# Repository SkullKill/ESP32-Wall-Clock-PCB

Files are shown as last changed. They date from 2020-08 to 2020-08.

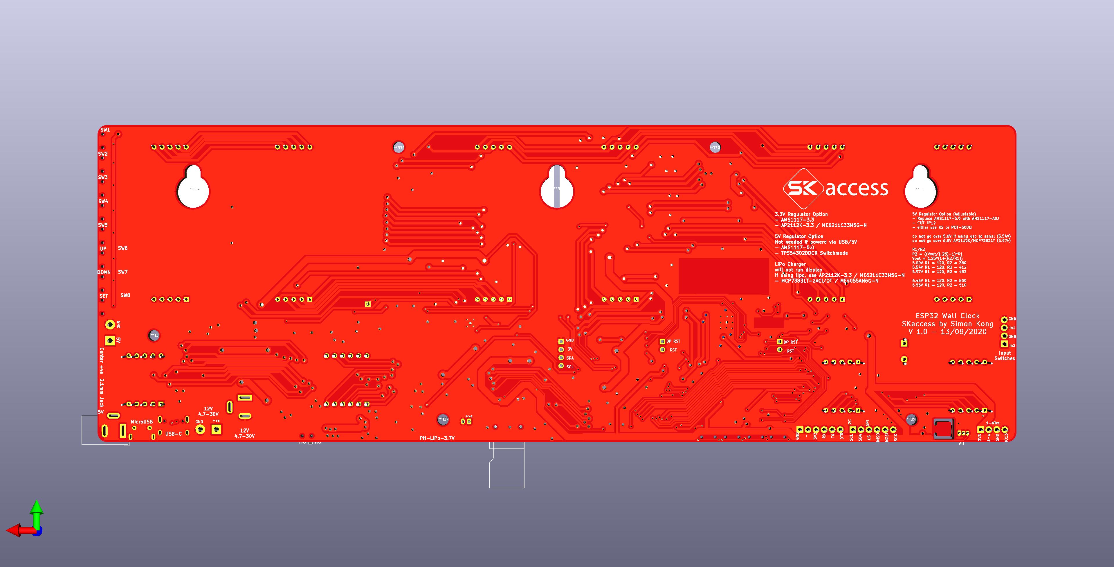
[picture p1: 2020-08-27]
ESP32-Wall-Clock/ESP32-Wall-Clock-Back-V1.0.jpg

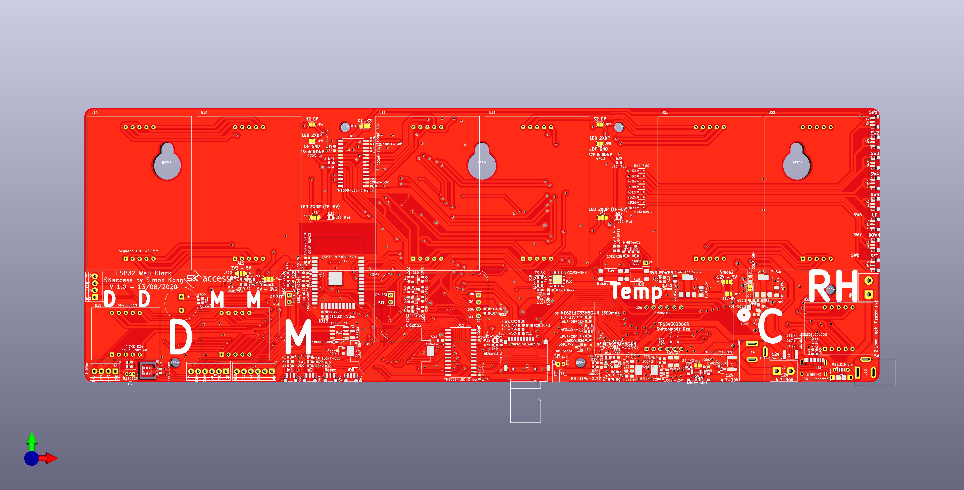
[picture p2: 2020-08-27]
ESP32-Wall-Clock/ESP32-Wall-Clock-Front-BoardOnly-V1.0.jpg

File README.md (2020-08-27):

# ESP32-Wall-Clock-PCB
ESP32 based 30cm Wall Mounted Clock. WiFi, NTP, SNMP, web interface, MicroUsb, Type-C, HG3613 Retrofit

Can be retrofitted into a HG3613 Case, or use standalone with the wall mounting on the pcb, or in a 3D Printed Case.

3D Printable Case not done yet...

this is still a work in progress.

PCB itself should be final, but the software is still being worked on. 

e.g Code for the light sensitivity sensor to automaticly adjust the display intensity

RTC PCF8563T code. 

OLED coding, etc....

ESP32-Wall-Clock-01.jpg


ESP32-Wall-Clock-Front-RT-V1.0a-WithOLEDboard.jpg


## V 1.0 26/08/2020 - Initial Release

  ------------------------------------------------------------
## PCB Board Used

Ready to use PCB Board (no up yet)

https://www.skstore.com.au/electronics/pcb/ESP32-Wall-Clock

PCB Design Files / gerber files

[ESP32-Wall-Clock-PCB](https://github.com/SkullKill/ESP32-Wall-Clock-PCB)

3D Printed Case design files / STL (no up yet)

[ESP32-Wall-Clock-PCB](https://github.com/SkullKill/ESP32-Wall-Clock-PCB)

FYI Gerber files are in the release section

https://github.com/SkullKill/ESP32-Wall-Clock-PCB/releases

more pictures in the wiki

https://github.com/SkullKill/ESP32-Wall-Clock-PCB/wiki

ESP32-Wall-Clock-HG3613-Retrofit-04.jpg


  ------------------------------------------------------------
## Schematics

ESP32-Wall-Clock-schematics-01-V1.0a.jpg


ESP32-Wall-Clock-schematics-02-V1.0.jpg


ESP32-Wall-Clock-schematics-03-V1.0.jpg


  ------------------------------------------------------------
## MecanicalDrawing

(Not Done Yet)

  ------------------------------------------------------------
## Code Used
(Not Done Yet)
[ESP32-Wall-Clock](https://github.com/SkullKill/ESP32-Wall-Clock)

  ------------------------------------------------------------

PCB features

* ESP32 Microprocessor
* onboard, IO0 / Reset switches
* breakout for UART (Programming/Serial monitor), i2c, SPI, 1-wire
* 5V input via MicroUSB, USB Type-C, 2.1mm barrel, Screw Type Terminal
* OR 5.6V to 26V if using Switchmode Reg, OR 6.4V-30V if using AMS1117-5.0 (input via 2.1mm barrel or Screw Type Terminal)
* PCF8563T RTC Clock with CR2032 Coin Cell Battery
* CP2102 USB to Serial, with Auto Reset (optional)
* RTC clock
* ALS-PT19 Light Intensity Sensor, to adjust Screen Brightness
* AHT20 Temperature / Humidity Sensor
* 1-Wire provision (possibility to add a number of DS18B20 temperature sensors)
* Built in buzzer
* 1-wire rail (possibility to add a number of DS18B20 temperature sensors)
* 2 physical button, + 8 physical button via TM1638, using diode, so that multiple button can be pressed at the same time.
* Ability to add external buttons.
* 1 configurable status light. (IO 13)
* 2 X TM1638 LED Segment Display Driver (in Common Anode Mode) [ one driving 6 digit, one driving 10 digit ]
* 6 X 1.8" / 45mm Segment display for Time Display (Common Anode Mode)
* 0.56" / 14.22mm Segment display for Date/Month / Temperature/Humidity (Common Anode Mode)
* Micro SD Card Slot
* Reverse polarity protection on 12V input
* PTC Fuse
* Level Shifter for ESP32 - TM1638 Comms

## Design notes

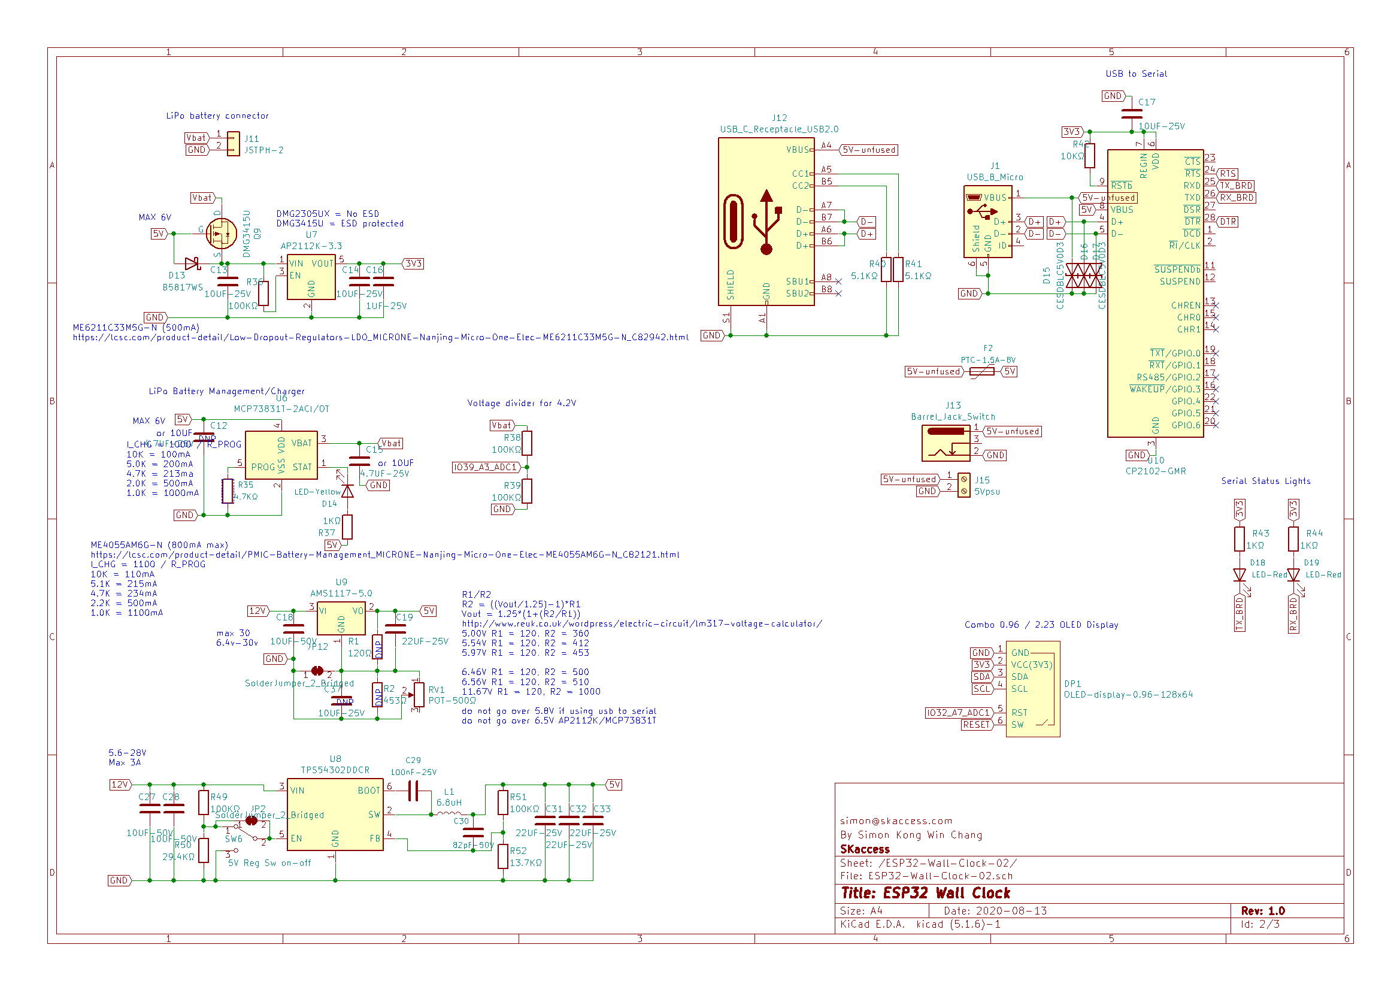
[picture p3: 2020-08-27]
ESP32-Wall-Clock/ESP32-Wall-Clock-schematics-02-V1.0.jpg

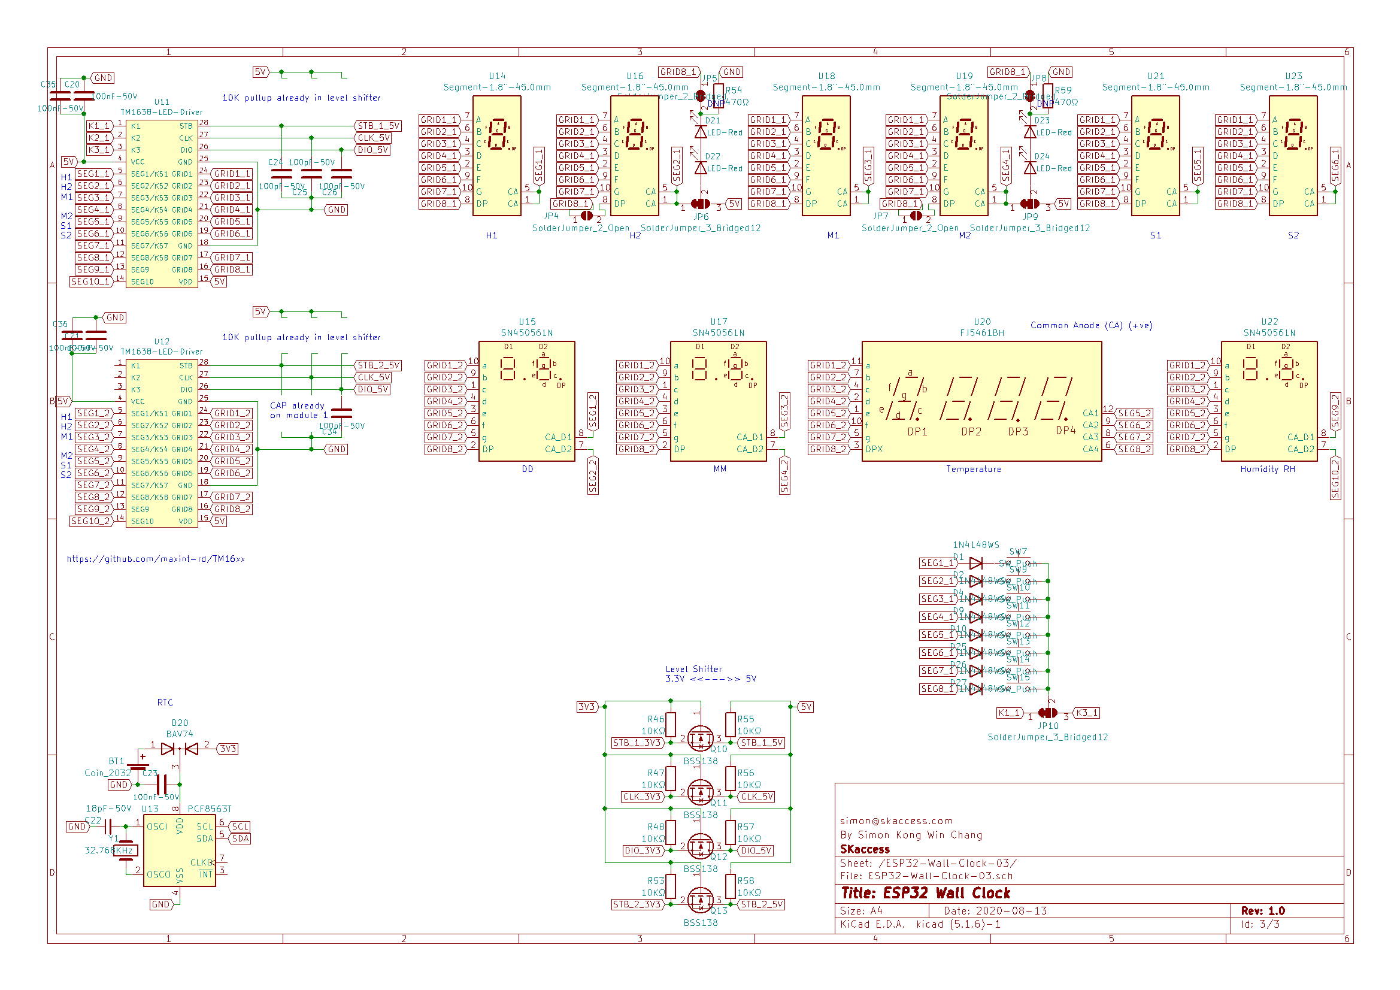
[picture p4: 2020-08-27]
ESP32-Wall-Clock/ESP32-Wall-Clock-schematics-03-V1.0.jpg

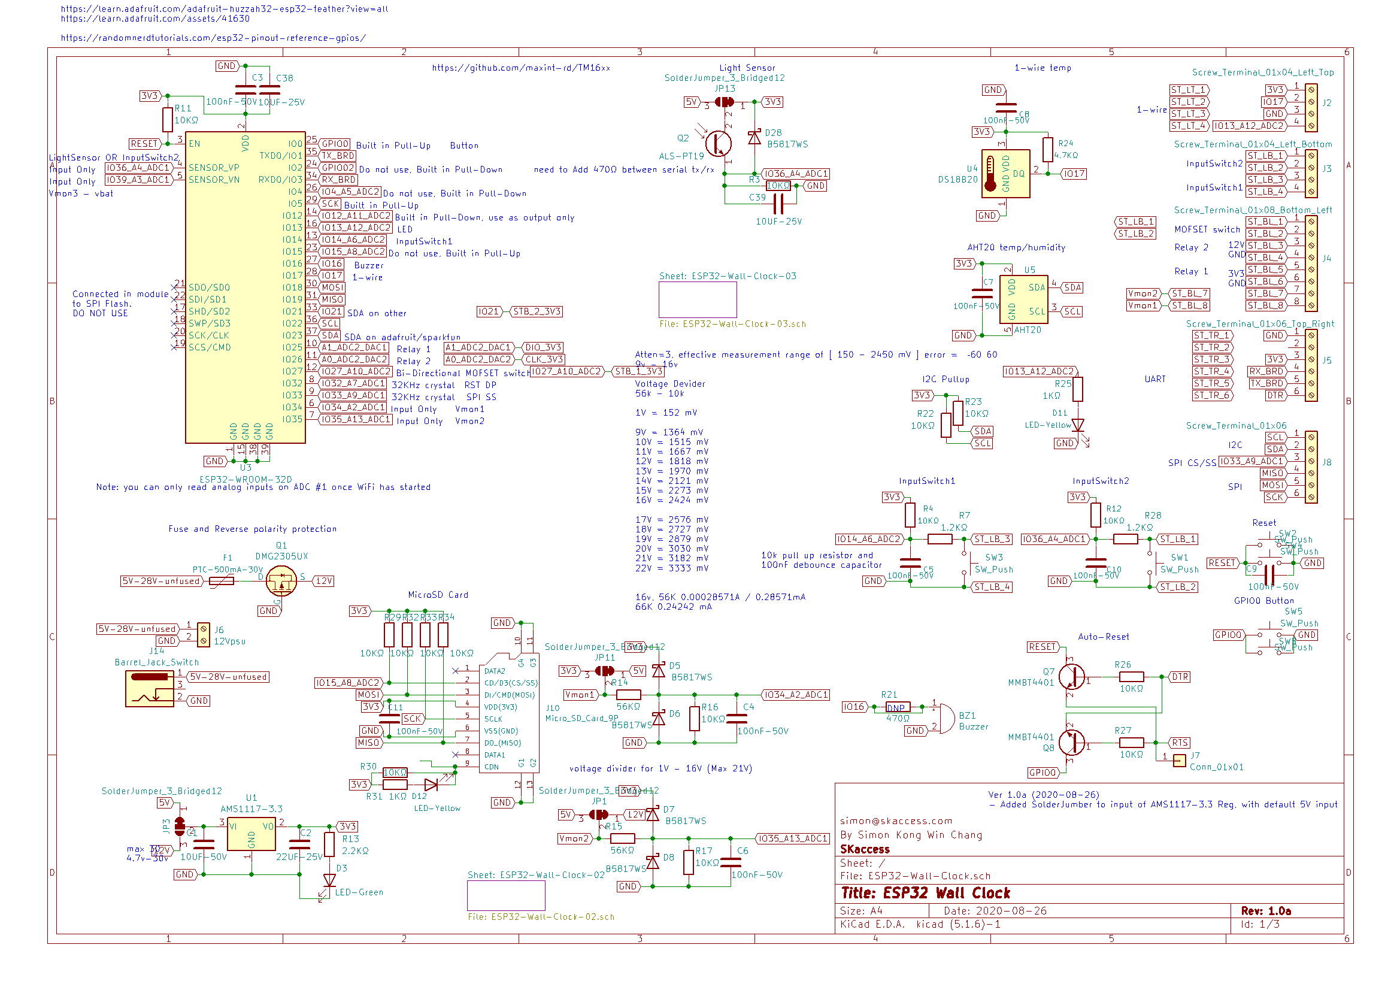
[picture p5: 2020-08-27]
ESP32-Wall-Clock/ESP32-Wall-Clock-schematics-01-V1.0a.jpg

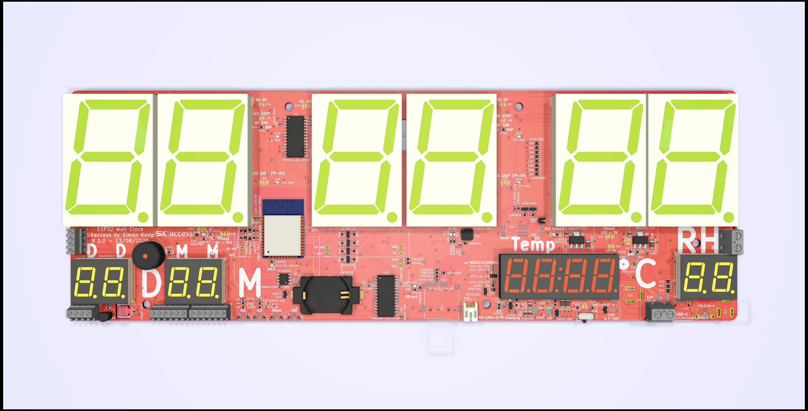
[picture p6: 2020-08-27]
ESP32-Wall-Clock/ESP32-Wall-Clock-Front-RT-V1.0.jpg

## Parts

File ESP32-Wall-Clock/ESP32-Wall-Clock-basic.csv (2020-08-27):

Reference | Quantity | Value | Footprint | Datasheet | LCSC | LCSCweb | MPN | MPNweb | web | ALT | at | removed
BT1 | 1 | Coin_2032 | Battery:BatteryHolder_Keystone_1060_1x2032 | https://datasheet.lcsc.com/szlcsc/1811061923_Q-J-CR2032-BS-6-1_C70377.pdf | C70377 | https://lcsc.com/product-detail/Battery-Holders-Clips-Contacts_Button-battery-holder-CR2032_C70377.html | CR2032-BS-6-1 |  |  | C238069
BZ1 | 1 | Buzzer | ESP32-12V-Voltage-Monitor:Buzzer_12x9.5RM5.0 | https://datasheet.lcsc.com/szlcsc/ZLFY-ZL-YDW1207-4005PA-5-0_C219727.pdf | C219727 | https://lcsc.com/product-detail/Buzzers_ZLFY-ZL-YDW1207-4005PA-5-0_C219727.html | ZL-YDW1207-4005PA-5.0
C1 C18 | 2 | 10UF-50V | Capacitor_SMD:C_1206_3216Metric | https://datasheet.lcsc.com/szlcsc/Samsung-Electro-Mechanics-CL31A106KBHNNNE_C13585.pdf | C13585 | https://lcsc.com/product-detail/Multilayer-Ceramic-Capacitors-MLCC-SMD-SMT_SAMSUNG_CL31A106KBHNNNE_10uF-106-10-50V_C13585.html | CL31A106KBHNNNE |  |  |  | reg | switchmode
C12 C15 | 0 | 4.7UF-25V | Capacitor_SMD:C_0603_1608Metric | https://datasheet.lcsc.com/szlcsc/1811110921_Samsung-Electro-Mechanics-CL10A106MA8NRNC_C96446.pdf | C69335 | https://lcsc.com/product-detail/Multilayer-Ceramic-Capacitors-MLCC-SMD-SMT_SAMSUNG_CL10A475KA8NQNC_4-7uF-475-10-25V_C69335.html | CL10A475KA8NQNC |  |  |  |  | charger
C16 | 0 | 1UF-25V | Capacitor_SMD:C_0603_1608Metric | https://datasheet.lcsc.com/szlcsc/1811071810_Samsung-Electro-Mechanics-CL10B105KA8NNNC_C29936.pdf | C29936 | https://lcsc.com/product-detail/Multilayer-Ceramic-Capacitors-MLCC-SMD-SMT_SAMSUNG_CL10B105KA8NNNC_1uF-105-10-25V-X7R_C29936.html | CL10B105KA8NNNC |  |  |  |  | AP2112K-3.3
C2 C19 | 2 | 22UF-25V | Capacitor_SMD:C_0805_2012Metric | https://datasheet.lcsc.com/szlcsc/Samsung-Electro-Mechanics-CL21A226MAQNNNE_C45783.pdf | C45783 | https://lcsc.com/product-detail/Multilayer-Ceramic-Capacitors-MLCC-SMD-SMT_SAMSUNG_CL21A226MAQNNNE_22uF-226-20-25V_C45783.html | CL21A226MAQNNNE |  |  | C86816 | reg | switchmode
C22 | 1 | 18pF-50V | Capacitor_SMD:C_0402_1005Metric | https://datasheet.lcsc.com/szlcsc/1811081533_Murata-Electronics-GCM1555C1H180JA16D_C126499.pdf | C126499 | https://lcsc.com/product-detail/Multilayer-Ceramic-Capacitors-MLCC-SMD-SMT_Murata-Electronics-GCM1555C1H180JA16D_C126499.html | GCM1555C1H180JA16D |  |  |  | RTC
C24 C25 C26 C34 | 4 | 100pF-50V | Capacitor_SMD:C_0402_1005Metric | https://datasheet.lcsc.com/szlcsc/1810191214_Samsung-Electro-Mechanics-CL05C101JB5NNNC_C26409.pdf | C26409 | https://lcsc.com/product-detail/Multilayer-Ceramic-Capacitors-MLCC-SMD-SMT_SAMSUNG_CL05C101JB5NNNC_100pF-101-5-50V_C26409.html | CL05C101JB5NNNC |  |  |  | TM1638
C29 | 0 | 100nF-25V | Capacitor_SMD:C_0402_1005Metric | https://datasheet.lcsc.com/szlcsc/1811141111_Samsung-Electro-Mechanics-CL05A104KA5NNNC_C100072.pdf | C100072 | https://lcsc.com/product-detail/Multilayer-Ceramic-Capacitors-MLCC-SMD-SMT_SAMSUNG_CL05A104KA5NNNC_100nF-104-10-25V_C100072.html | CL05A104KA5NNNC |  |  |  |  | switchmode
C30 | 0 | 82pF-50V | Capacitor_SMD:C_0402_1005Metric | https://datasheet.lcsc.com/szlcsc/Samsung-Electro-Mechanics-CL05C820JB5NNNC_C13532.pdf | C13532 | https://lcsc.com/product-detail/Multilayer-Ceramic-Capacitors-MLCC-SMD-SMT_SAMSUNG_CL05C820JB5NNNC_82pF-820-5-50V_C13532.html | CL05C820JB5NNNC |  |  |  |  | switchmode
C38 C39 | 2 | 10UF-25V | Capacitor_SMD:C_0603_1608Metric | https://datasheet.lcsc.com/szlcsc/1811110921_Samsung-Electro-Mechanics-CL10A106MA8NRNC_C96446.pdf | C96446 | https://lcsc.com/product-detail/Multilayer-Ceramic-Capacitors-MLCC-SMD-SMT_Samsung-Electro-Mechanics-CL10A106MA8NRNC_C96446.html | CL10A106MA8NRNC |  |  |  | ESP32, LightSensor | 5v var reg, 3.3v reg, usb serial
C5 C4 C3 C9 C8 C6 C7 C10 C20 C23 C21 C35 C36 | 13 | 100nF-50V | Capacitor_SMD:C_0603_1608Metric | https://datasheet.lcsc.com/szlcsc/YAGEO-AC0603KRX7R9BB104_C149620.pdf | C149620 | https://lcsc.com/product-detail/Multilayer-Ceramic-Capacitors-MLCC-SMD-SMT_YAGEO-AC0603KRX7R9BB104_C149620.html | AC0603KRX7R9BB104 |  |  |  |  | sd card
D1 D2 D4 D9 D10 D25 D26 D27 | 8 | 1N4148WS | Diode_SMD:D_SOD-323 | https://datasheet.lcsc.com/szlcsc/Changjiang-Electronics-Tech-CJ-1N4148WS_C2128.pdf | C2128 | https://lcsc.com/product-detail/Switching-Diode_Changjiang-Electronics-Tech-CJ-1N4148WS_C2128.html | 1N4148WS |  |  |  | switch array
D11 | 1 | LED-Yellow | LED_SMD:LED_0603_1608Metric | https://datasheet.lcsc.com/szlcsc/Foshan-NationStar-Optoelectronics-FC-DA1608HYK-588J_C84268.pdf | C84268 | https://lcsc.com/product-detail/Light-Emitting-Diodes-LED_Yellow-light-SMDLED-70-150mcd_C84268.html | FC-DA1608HYK-588J |  |  |  | io 13 | charger, SD card
D15 | 1 | CESDBLC5V0D3 | Diode_SMD:D_SOD-323 | https://datasheet.lcsc.com/szlcsc/1811122110_Changjiang-Electronics-Tech-CJ-CESDBLC5V0D3_C47346.pdf | C47346 | https://lcsc.com/product-detail/Diodes-ESD_Changjiang-Electronics-Tech-CJ-CESDBLC5V0D3_C47346.html | CESDBLC5V0D3 |  |  |  | usb power | usb data
D24 D23 D22 D21 | 4 | LED-Red | LED_SMD:LED_0603_1608Metric | https://datasheet.lcsc.com/szlcsc/Foshan-NationStar-Optoelectronics-FC-DA1608HRK-620D_C84263.pdf | C84263 | https://lcsc.com/product-detail/Light-Emitting-Diodes-LED_Red-LED-SMDLED-80-100mcd_C84263.html | FC-DA1608HRK-620D |  |  |  | clock dots | Serial tx/rx
D20 | 1 | BAV74 | Package_TO_SOT_SMD:SOT-23 | https://datasheet.lcsc.com/szlcsc/1809211016_Changjiang-Electronics-Tech-CJ-BAV74_C68981.pdf | C68981 | https://lcsc.com/product-detail/Switching-Diode_Changjiang-Electronics-Tech-CJ-BAV74_C68981.html | BAV74 |  |  |  | RTC
D3 | 0 | LED-Green | LED_SMD:LED_0603_1608Metric | https://datasheet.lcsc.com/szlcsc/Orient-ORH-G36G_C205443.pdf | C205443 | https://lcsc.com/product-detail/Light-Emitting-Diodes-LED_0603-green_C205443.html | ORH-G36G |  |  |  |  | power
D5 D6 D7 D8 | 4 | B5817WS | Diode_SMD:D_SOD-323 | https://datasheet.lcsc.com/szlcsc/1811051320_MDD-Microdiode-Electronics-B5817WS-SJ_C114023.pdf | C114023 | https://lcsc.com/product-detail/Schottky-Barrier-Diodes-SBD_MDD-Microdiode-Electronics-B5817WS-SJ_C114023.html | B5817WS-SJ |  |  |  | voltage divider | 3v3 reg
DP1 | 1 | OLED-display-0.96-128x64 | ESP32-Wall-Clock:OLED-display-0.96-128x64-2.23-128x32-combo
F1 | 1 | PTC-500mA-30V | Fuse:Fuse_1812_4532Metric | https://datasheet.lcsc.com/szlcsc/1912111437_Jinrui-Electronic-Materials-Co-JK-MSMD050-30_C369168.pdf | C369168 | https://lcsc.com/product-detail/PTC-Resettable-Fuses_Jinrui-Electronic-Materials-Co-JK-MSMD050-30_C369168.html | JK-MSMD050-30 |  |  |  | 12v input
F2 | 1 | PTC-1.5A-8V | Fuse:Fuse_1812_4532Metric | https://datasheet.lcsc.com/szlcsc/1810111821_Littelfuse-1812L150ZR_C207071.pdf | C207071 | https://lcsc.com/product-detail/Surface-Mount-Fuses_Littelfuse_1812L150ZR_Littelfuse-1812L150ZR_C207071.html | 1812L150ZR |  |  |  | 5v input
J1 | 1 | USB_B_Micro | ESP32-12V-Voltage-Monitor:USB_Micro-B_Korean_U-F-M5DD-Y-L | https://datasheet.lcsc.com/szlcsc/1811131825_Korean-Hroparts-Elec-U-F-M5DD-Y-L_C91146.pdf | C91146 | https://lcsc.com/product-detail/USB-Connectors_Korean-Hroparts-Elec-U-F-M5DD-Y-L_C91146.html | U-F-M5DD-Y-L
J10 | 0 | Micro_SD_Card_9P | ESP32-12V-Voltage-Monitor:Micro_SD_9+4P-SMD-16.1X14.5X1.85MM | https://datasheet.lcsc.com/szlcsc/2002271812_XKB-Connectivity-XKTF-015-N_C381082.pdf | C381082 | https://lcsc.com/product-detail/Card-Sockets-Connectors_XKB-Connectivity-XKTF-015-N_C381082.html | XKTF-015-N
J11 | 0 | JSTPH-2 | Connector_JST:JST_PH_S2B-PH-K_1x02_P2.00mm_Horizontal | http://boomele.com/proshow.asp?id=15 | C49992 | https://lcsc.com/product-detail/Wire-To-Board-Wire-To-Wire-Connector_BOOMELE-Boom-Precision-Elec-PH-2AWD_C49992.html | S2B-PH-K-S |  |  |  |  | lipo batt
J12 | 1 | USB_C_Receptacle_USB2.0 | Connector_USB:USB_C_Receptacle_HRO_TYPE-C-31-M-12 | https://datasheet.lcsc.com/szlcsc/1811131825_Korean-Hroparts-Elec-TYPE-C-31-M-12_C165948.pdf | C165948 | https://lcsc.com/product-detail/USB-Type-C_Korean-Hroparts-Elec-TYPE-C-31-M-12_C165948.html | TYPE-C-31-M-12
J14 J13 | 2 | Barrel_Jack_Switch | Connector_BarrelJack:BarrelJack_Wuerth_6941xx301002 | https://datasheet.lcsc.com/szlcsc/1811051112_BOOMELE-Boom-Precision-Elec-DC-005-5-5-2-0MM_C16214.pdf | C16214 | https://lcsc.com/product-detail/AC-DC-Power-Plugs-Receptacles_BOOMELE-Boom-Precision-Elec-DC-005-5-5-2-0MM_C16214.html | DC-005 5.5-2.0MM
J15 | 0 | 5Vpsu | pi-template:TerminalBlock_bornier-2_P5.08mm | https://datasheet.lcsc.com/szlcsc/Ningbo-Kangnex-Elec-WJ126V-5-0-2P_C8404.pdf | C8404 | https://lcsc.com/product-detail/Pluggable-System-Terminal-Block_Ningbo-Kangnex-Elec-WJ126V-5-0-2P_C8404.html | WJ126V-5.0-2P
J2 | 0 | Screw_Terminal_01x04_Left_Top | pi-template:TerminalBlock_TE_282834-4_1x04_P2.54mm_Horizontal | ~ |  |  | KF128-2.54-4P | http://en.cnkefa.com/index.php?c=product&id=159 | https://www.aliexpress.com/store/group/Connection-terminal/4657016_515213135.html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
J3 | 0 | Screw_Terminal_01x04_Left_Bottom | pi-template:TerminalBlock_TE_282834-4_1x04_P2.54mm_Horizontal | ~ |  |  | KF128-2.54-4P | http://en.cnkefa.com/index.php?c=product&id=159 | https://www.aliexpress.com/store/group/Connection-terminal/4657016_515213135.html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
J4 | 0 | Screw_Terminal_01x08_Bottom_Left | pi-template:TerminalBlock_TE_282834-8_1x08_P2.54mm_Horizontal | ~ |  |  | KF128-2.54-8P | http://en.cnkefa.com/index.php?c=product&id=159
J5 | 0 | Screw_Terminal_01x06_Top_Right | pi-template:TerminalBlock_TE_282834-6_1x06_P2.54mm_Horizontal | ~ |  |  | KF128-2.54-6P | http://en.cnkefa.com/index.php?c=product&id=159
J6 | 0 | 12Vpsu | pi-template:TerminalBlock_bornier-2_P5.08mm | https://datasheet.lcsc.com/szlcsc/Ningbo-Kangnex-Elec-WJ126V-5-0-2P_C8404.pdf | C8404 | https://lcsc.com/product-detail/Pluggable-System-Terminal-Block_Ningbo-Kangnex-Elec-WJ126V-5-0-2P_C8404.html | WJ126V-5.0-2P
J7 | 1 | Conn_01x01 | Connector_PinHeader_2.54mm:PinHeader_1x01_P2.54mm_Vertical | ~
J8 | 0 | Screw_Terminal_01x06 | pi-template:TerminalBlock_TE_282834-6_1x06_P2.54mm_Horizontal | ~ |  |  | KF128-2.54-6P | http://en.cnkefa.com/index.php?c=product&id=159
J9 | 0 | Screw_Terminal_01x02 | pi-template:TerminalBlock_TE_282834-2_1x02_P2.54mm_Horizontal | ~ |  |  | KF128-2.54-2P | http://en.cnkefa.com/index.php?c=product&id=159
JP1 JP11 JP13 JP9 JP6 JP10 | 6 | SolderJumper_3_Bridged12 | Jumper:SolderJumper-3_P1.3mm_Bridged12_RoundedPad1.0x1.5mm | ~
JP12 | 1 | SolderJumper_2_Bridged | Jumper:SolderJumper-2_P1.3mm_Bridged2Bar_RoundedPad1.0x1.5mm | ~
JP2 JP5 JP8 | 3 | SolderJumper_2_Bridged | Jumper:SolderJumper-2_P1.3mm_Bridged_RoundedPad1.0x1.5mm | ~
JP3 JP7 JP4 | 3 | SolderJumper_2_Open | Jumper:SolderJumper-2_P1.3mm_Open_RoundedPad1.0x1.5mm | ~
L1 | 0 | 6.8uH | ESP32-12V-Voltage-Monitor:L_7.3x7.3_H4.5 | https://datasheet.lcsc.com/szlcsc/1810181823_cjiang-Changjiang-Microelectronics-Tech-FXL0630-6R8-M_C167221.pdf | C167221 | https://lcsc.com/product-detail/Power-Inductors_cjiang-Changjiang-Microelectronics-Tech-FXL0630-6R8-M_C167221.html | FXL0630-6R8-M |  |  |  |  | switchmode
Q1 | 1 | DMG2305UX | Package_TO_SOT_SMD:SOT-23 | https://datasheet.lcsc.com/szlcsc/Diodes-Incorporated-DMG2305UX-13_C144153.pdf | C144153 | https://lcsc.com/product-detail/MOSFET_Diodes-Incorporated_DMG2305UX-13_Diodes-Incorporated-DMG2305UX-13_C144153.html | DMG2305UX-13 |  |  |  | 12v reverse polarity protection
Q10 Q11 Q12 Q13 | 4 | BSS138 | Package_TO_SOT_SMD:SOT-23 | https://datasheet.lcsc.com/szlcsc/Diodes-Incorporated-BSS138-7-F_C40912.pdf | C40912 | https://lcsc.com/product-detail/MOSFET_Diodes-Incorporated_BSS138-7-F_Diodes-Incorporated-BSS138-7-F_C40912.html | BSS138-7-F |  |  |  | level shifter
Q2 | 1 | ALS-PT19 | LED_SMD:LED_0603_1608Metric | https://datasheet.lcsc.com/szlcsc/1806131537_Everlight-Elec-ALS-PT19-315C-L177-TR8_C146233.pdf | C146233 | https://lcsc.com/product-detail/Photoresistors_ALS-PT19-315C-L177-TR8_C146233.html | ALS-PT19-315C/L177/TR8 |  |  |  | light sensor
Q8 Q7 | 0 | MMBT4401 | Package_TO_SOT_SMD:SOT-23 | https://datasheet.lcsc.com/szlcsc/ON-Semicon-ON-MMBT4401LT1G_C31776.pdf | C31776 | https://lcsc.com/product-detail/Transistors-NPN-PNP_ON-Semicon_MMBT4401LT1G_ON-Semicon-ON-MMBT4401LT1G_C31776.html | MMBT4401LT1G |  |  |  |  | auto reset
Q9 | 0 | DMG3415U | Package_TO_SOT_SMD:SOT-23 | https://datasheet.lcsc.com/szlcsc/1809191942_Diodes-Incorporated-DMG3415U-7_C96616.pdf | C96616 | https://lcsc.com/product-detail/MOSFET_Diodes-Incorporated_DMG3415U-7_Diodes-Incorporated-DMG3415U-7_C96616.html | DMG3415U-7 |  |  |  |  | charger
R1 | 0 | 120Ω | Resistor_SMD:R_0603_1608Metric | https://datasheet.lcsc.com/szlcsc/1811021219_YAGEO-RC0603FR-07120RL_C114640.pdf | C114640 | https://lcsc.com/product-detail/Chip-Resistor-Surface-Mount_YAGEO-RC0603FR-07120RL_C114640.html | RC0603FR-07120RL |  |  |  |  | 5v reg adj
R13 | 0 | 2.2KΩ | Resistor_SMD:R_0603_1608Metric | https://datasheet.lcsc.com/szlcsc/YAGEO-RC0603FR-072K2L_C114662.pdf | C114662 | https://lcsc.com/product-detail/Chip-Resistor-Surface-Mount_2-2KR-2201-1_C114662.html | RC0603FR-072K2L |  |  |  |  | 3v3 power
R14 R15 | 2 | 56KΩ | Resistor_SMD:R_0603_1608Metric | https://datasheet.lcsc.com/szlcsc/1811021312_YAGEO-RC0603FR-0756KL_C114630.pdf | C114630 | https://lcsc.com/product-detail/Chip-Resistor-Surface-Mount_YAGEO-RC0603FR-0756KL_C114630.html | RC0603FR-0756KL |  |  |  | voltage divider
R2 | 0 | 453Ω | Resistor_SMD:R_0603_1608Metric | https://datasheet.lcsc.com/szlcsc/2007151233_YAGEO-RC0603FR-07453RL_C482871.pdf | C482871 | https://lcsc.com/product-detail/New-Arrivals_YAGEO-RC0603FR-07453RL_C482871.html | RC0603FR-07453RL |  |  |  |  | 5v reg adj
R21 R54 R59 | 0 | 470Ω | Resistor_SMD:R_0603_1608Metric | https://datasheet.lcsc.com/szlcsc/1810161617_YAGEO-RC0603FR-07470RL_C114669.pdf | C114669 | https://lcsc.com/product-detail/Chip-Resistor-Surface-Mount_YAGEO-RC0603FR-07470RL_C114669.html | RC0603FR-07470RL |  |  |  |  | buzzer, clock dot
R24 | 1 | 4.7KΩ | Resistor_SMD:R_0603_1608Metric | https://datasheet.lcsc.com/szlcsc/YAGEO-RC0603FR-074K7L_C99782.pdf | C99782 | https://lcsc.com/product-detail/Chip-Resistor-Surface-Mount_4-7KR-472-1_C99782.html | RC0603FR-074K7L |  |  |  | 1-wire | charger
R25 | 1 | 1KΩ | Resistor_SMD:R_0603_1608Metric | https://datasheet.lcsc.com/szlcsc/YAGEO-RC0603FR-071KL_C22548.pdf | C22548 | https://lcsc.com/product-detail/Chip-Resistor-Surface-Mount_1KR-1001-1_C22548.html | RC0603FR-071KL |  |  |  | io13 | serial tx/rx, microSD, charger
 | 0 | 100KΩ | Resistor_SMD:R_0603_1608Metric | https://datasheet.lcsc.com/szlcsc/1809281124_YAGEO-RC0603FR-07100KL_C14675.pdf | C14675 | https://lcsc.com/product-detail/Chip-Resistor-Surface-Mount_100KR-1003-1_C14675.html | RC0603FR-07100KL |  |  |  |  | 3v3 reg, bat voltage divider, switchmode
R4 R16 R11 R17 R22 R23 R12 R3 R46 R55 R47 R56 R48 R57 R53 R58 | 16 | 10KΩ | Resistor_SMD:R_0603_1608Metric | https://datasheet.lcsc.com/szlcsc/YAGEO-RC0603FR-0710KL_C98220.pdf | C98220 | https://lcsc.com/product-detail/Chip-Resistor-Surface-Mount_10KR-1002-1_C98220.html | RC0603FR-0710KL |  |  |  |  | usbSerial, Sdcard, autoReset
R40 R41 | 2 | 5.1KΩ | Resistor_SMD:R_0603_1608Metric | https://datasheet.lcsc.com/szlcsc/YAGEO-RC0603FR-075K1L_C105580.pdf | C105580 | https://lcsc.com/product-detail/Chip-Resistor-Surface-Mount_5-1KR-5101-1_C105580.html | RC0603FR-075K1L |  |  |  | usb-c
R50 | 0 | 29.4KΩ | Resistor_SMD:R_0603_1608Metric | https://datasheet.lcsc.com/szlcsc/YAGEO-RC0603FR-0729K4L_C137752.pdf | C137752 | https://lcsc.com/product-detail/_RC0603FR-0729K4L_C137752.html | RC0603FR-0729K4L |  |  |  |  | switchmode
R52 | 0 | 13.7KΩ | Resistor_SMD:R_0603_1608Metric | https://datasheet.lcsc.com/szlcsc/2007151214_YAGEO-RC0603FR-0713K7L_C482771.pdf | C482771 | https://lcsc.com/product-detail/New-Arrivals_YAGEO-RC0603FR-0713K7L_C482771.html | RC0603FR-0713K7L |  |  |  |  | switchmode
R7 R28 | 2 | 1.2KΩ | Resistor_SMD:R_0603_1608Metric | https://datasheet.lcsc.com/szlcsc/YAGEO-RC0603FR-071K2L_C114605.pdf | C114605 | https://lcsc.com/product-detail/Chip-Resistor-Surface-Mount_1-2KR-1201-1_C114605.html | RC0603FR-071K2L |  |  |  | input switch
RV1 | 0 | POT-500Ω | Potentiometer_SMD:Potentiometer_Bourns_TC33X_Vertical | https://datasheet.lcsc.com/szlcsc/1811041530_HDK-Hokuriku-Elec-Industry-VG039NCHXTB501_C128556.pdf | C128556 | https://lcsc.com/product-detail/Variable-Resistors_HDK-Hokuriku-Elec-Industry-VG039NCHXTB501_C128556.html | VG039NCHXTB501 |  |  |  |  | 5v reg adj
SW3 SW1 SW8 SW2 SW7 SW9 SW10 SW11 SW12 SW13 SW14 SW15 | 7 to 12 | SW_Push | Button_Switch_SMD:SW_Push_1P1T-MP_NO_Horizontal_Alps_SKRTLAE010 | https://datasheet.lcsc.com/szlcsc/1809191932_ALPS-Electric-SKRTLAE010_C110293.pdf | C110293 | https://lcsc.com/product-detail/Tactile-Switches_ALPS-Electric-SKRTLAE010_C110293.html | SKRTLAE010
SW4 SW5 | 2 | SW_Push | ESP32-12V-Voltage-Monitor:SW_SPST_TL3305A | https://datasheet.lcsc.com/szlcsc/2002271432_XKB-Enterprise-TS-1185EC-C-D-B_C318893.pdf | C174049 | https://lcsc.com/product-detail/Tactile-Switches_Switch-4-5-4-5-3-8mm_C174049.html
SW6 | 0 | 5V Reg Sw on-off | Button_Switch_SMD:SW_SPDT_PCM12 | https://datasheet.lcsc.com/szlcsc/Korean-Hroparts-Elec-K3-1296S-E2_C136659.pdf | C136659 | https://lcsc.com/product-detail/Toggle-Switches_Korean-Hroparts-Elec-K3-1296S-E2_C136659.html | K3-1296S-E2 |  |  |  |  | switchmode
U1 | 1 | AMS1117-3.3 | Package_TO_SOT_SMD:SOT-223-3_TabPin2 | https://datasheet.lcsc.com/szlcsc/1912111437_Slkor-SLKORMICRO-Elec-AMS1117-3-3_C426566.pdf | C426566 | https://lcsc.com/product-detail/Low-Dropout-Regulators-LDO_Slkor-SLKORMICRO-Elec-AMS1117-3-3_C426566.html | AMS1117-3.3
U10 | 0 | CP2102-GMR | Package_DFN_QFN:QFN-28-1EP_5x5mm_P0.5mm_EP3.35x3.35mm | https://www.silabs.com/documents/public/data-sheets/cp2102n-datasheet.pdf | C6568 | https://lcsc.com/product-detail/USB-ICs_SILICON-LABS-CP2102-GMR_C6568.html | CP2102-GMR |  |  |  |  | usbSerial
U11 U12 | 2 | TM1638-LED-Driver | Package_SO:SOIC-28W_7.5x17.9mm_P1.27mm | https://raw.githubusercontent.com/maxint-rd/TM16xx/master/documents/LED%20driver%20TM1638en.pdf | C19187 | https://lcsc.com/product-detail/LED-Drivers_TM-Shenzhen-Titan-Micro-Elec-TM1638_C19187.html | TM1638
U13 | 1 | PCF8563T | Package_SO:SOIC-8_3.9x4.9mm_P1.27mm | https://assets.nexperia.com/documents/data-sheet/PCF8563.pdf | C7440 | https://lcsc.com/product-detail/Real-time-Clocks_NXP-Semicon-PCF8563T-5-518_C7440.html | PCF8563T/5,518 |  |  |  | RTC
U14 U16 U18 U19 U21 U23 | 6 | Segment-1.8-45.0mm" | ESP32-Wall-Clock:SM471801N | https://datasheet.lcsc.com/szlcsc/1811151426_ARKLED-Wuxi-ARK-Tech-Elec-SM471801N_C193718.pdf | C193718 | https://lcsc.com/product-detail/Led-Segment-Display_ARKLED-Wuxi-ARK-Tech-Elec-SM471801N_C193718.html | SM471801N |  |  |  | Single
U15 U17 U22 | 3 | SN450561N | ESP32-Wall-Clock:SN450561N | https://datasheet.lcsc.com/szlcsc/1811151433_ARKLED-Wuxi-ARK-Tech-Elec-SN450561N_C193143.pdf | C193143 | https://lcsc.com/product-detail/Led-Segment-Display_ARKLED-Wuxi-ARK-Tech-Elec-SN450561N_C193143.html | SN450561N |  |  |  | Double
U20 | 1 | FJ5461BH | Display_7Segment:CA56-12SRWA | https://datasheet.lcsc.com/szlcsc/1811060611_Shenzhen-Zhihao-Elec-C38183_C38183.pdf | C38183 | https://lcsc.com/product-detail/Led-Segment-Display_Made-in-China-4Bit0-56Inch-red-digital-Led_C38183.html | C38183 |  |  |  | 4 digit
U3 | 1 | ESP32-WROOM-32D | RF_Module:ESP32-WROOM-32 | https://www.espressif.com/sites/default/files/documentation/esp32-wroom-32d_esp32-wroom-32u_datasheet_en.pdf | C473012 | https://lcsc.com/product-detail/WIFI-Modules_Espressif-Systems-ESP32-WROOM-32D_C473012.html
U4 | 0 | DS18B20 | Package_TO_SOT_THT:TO-92_Inline | http://datasheets.maximintegrated.com/en/ds/DS18B20.pdf | C9753 | https://lcsc.com/product-detail/Temperature-Sensors_MAXIM_DS18B20_DS18B20_C9753.html | DS18B20+
U5 | 1 | AHT20 | ESP32-Wall-Clock:AHT20 | http://www.aosong.com/userfiles/files/media/AHT20%E8%8B%B1%E6%96%87%E7%89%88%E4%BA%A7%E5%93%81%E6%89%8B%E5%86%8C%20A0%202020-4-16.pdf | C503357 | https://lcsc.com/product-detail/Temperature-Humidity-Sensors_Aosong-Guangzhou-Elec-AHT20_C503357.html | AHT20 |  |  |  | temp/humidity
U6 | 0 | MCP73831T-2ACI/OT | Package_TO_SOT_SMD:SOT-23-5 | http://ww1.microchip.com/downloads/en/DeviceDoc/20001984g.pdf | C424093 | https://lcsc.com/product-detail/PMIC-Battery-Management_Microchip-Tech-MCP73831T-2ACI-OT_C424093.html | MCP73831T-2ACI/OT |  |  | C82121 |  | charger
U7 | 0 | AP2112K-3.3 | Package_TO_SOT_SMD:SOT-23-5 | https://www.diodes.com/assets/Datasheets/AP2112.pdf | C51118 | https://lcsc.com/product-detail/Low-Dropout-Regulators-LDO_DIODES_AP2112K-3-3TRG1_AP2112K-3-3TRG1_C51118.html | AP2112K-3.3TRG1 |  |  | C82942 |  | 3v3 reg
U8 | 0 | TPS54302DDCR | Package_TO_SOT_SMD:SOT-23-6 |  | C311983 | https://lcsc.com/product-detail/Others_Texas-Instruments_TPS54302DDCR_Texas-Instruments-TI-TPS54302DDCR_C311983.html | TPS54302DDCR |  |  |  |  | switchmode
U9 | 1 | AMS1117-5.0 | Package_TO_SOT_SMD:SOT-223-3_TabPin2 | https://datasheet.lcsc.com/szlcsc/1912241104_Slkor-SLKORMICRO-Elec-AMS1117-5-0_C473812.pdf | C473812 | https://lcsc.com/product-detail/Low-Dropout-Regulators-LDO_Slkor-SLKORMICRO-Elec-AMS1117-5-0_C473812.html | AMS1117-5.0
Y1 | 1 | 32.768KHz | Crystal:Crystal_SMD_3215-2Pin_3.2x1.5mm | https://datasheet.lcsc.com/szlcsc/1811021520_Yangxing-Tech-X321532768KGB2SI_C94279.pdf | C94279 | https://lcsc.com/product-detail/SMD-Crystal-Resonators_Yangxing-Tech-X321532768KGB2SI_C94279.html | X321532768KGB2SI

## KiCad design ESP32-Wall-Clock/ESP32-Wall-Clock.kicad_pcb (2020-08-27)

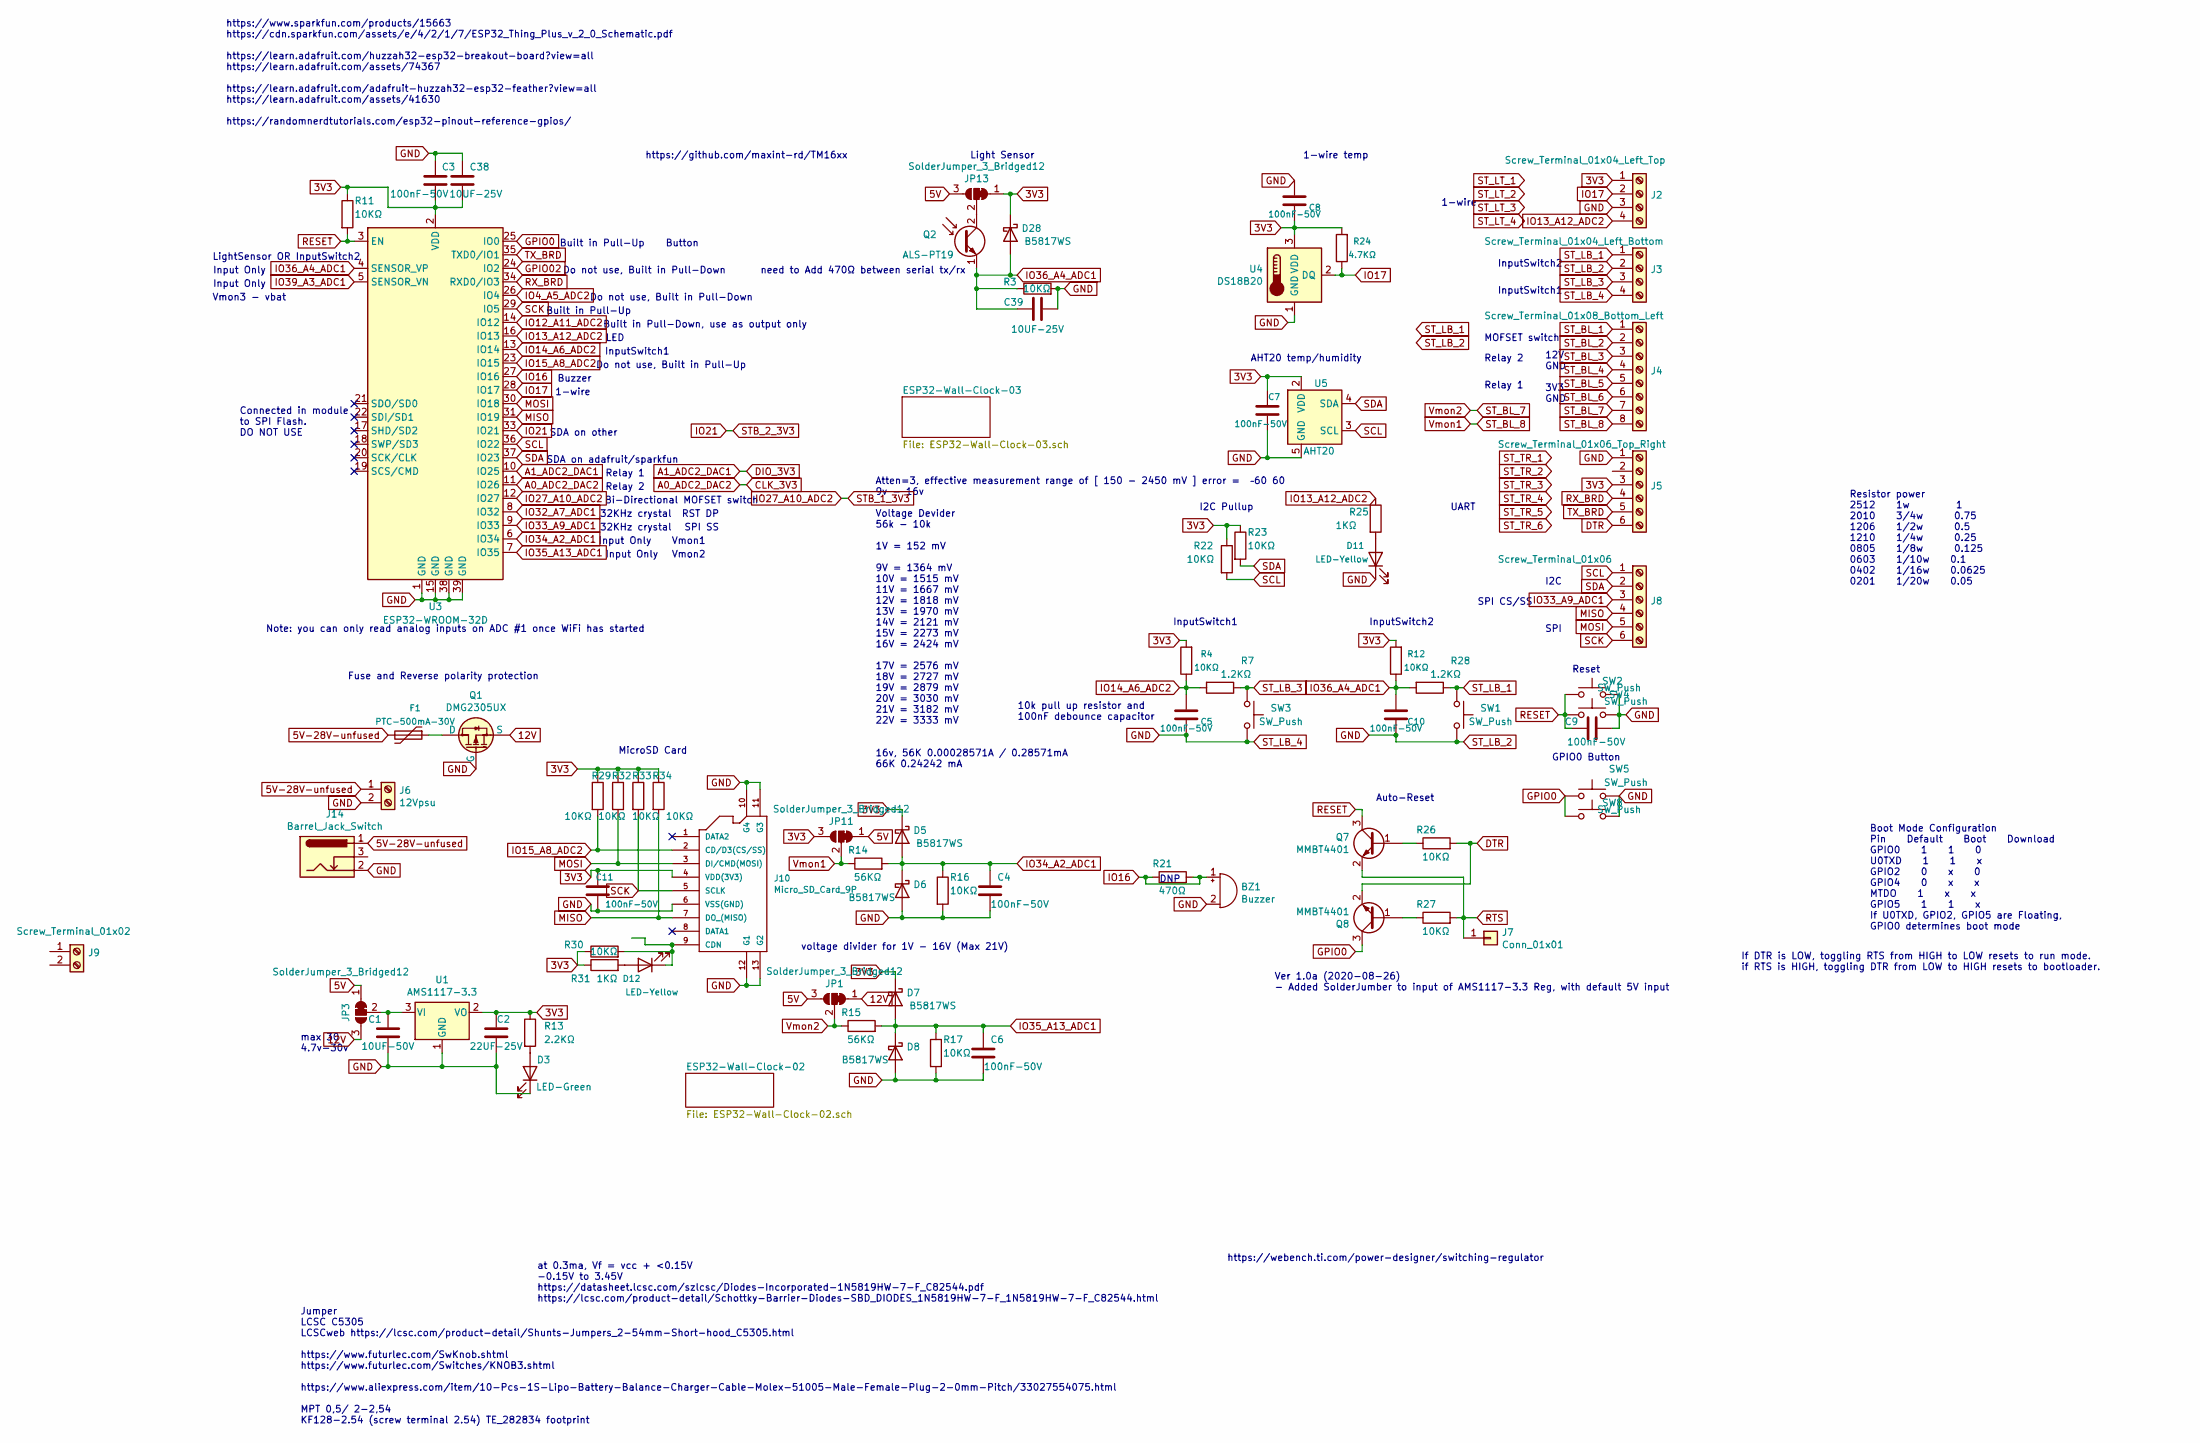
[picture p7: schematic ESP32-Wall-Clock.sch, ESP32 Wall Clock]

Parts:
BZ1: Buzzer; Buzzer_12x9.5RM5.0; MPN ZL-YDW1207-4005PA-5.0; LCSC C219727
C1: 10UF-50V; C_1206_3216Metric; MPN CL31A106KBHNNNE; LCSC C13585
C2: 22UF-25V; C_0805_2012Metric; MPN CL21A226MAQNNNE; LCSC C45783
C3, C4, C5, C6, C7, C8, C9, C10, C11: 100nF-50V; C_0603_1608Metric; MPN AC0603KRX7R9BB104; LCSC C149620
C38, C39: 10UF-25V; C_0603_1608Metric; MPN CL10A106MA8NRNC; LCSC C96446
D3: LED-Green; LED_0603_1608Metric; MPN ORH-G36G; LCSC C205443
D5, D6, D7, D8, D28: B5817WS; D_SOD-323; MPN B5817WS-SJ; LCSC C114023
D11, D12: LED-Yellow; LED_0603_1608Metric; MPN FC-DA1608HYK-588J; LCSC C84268
F1: PTC-500mA-30V; Fuse_1812_4532Metric; MPN JK-MSMD050-30; LCSC C369168
J2: Screw_Terminal_01x04_Left_Top; TerminalBlock_TE_282834-4_1x04_P2.54mm_Horizontal; MPN KF128-2.54-4P
J3: Screw_Terminal_01x04_Left_Bottom; TerminalBlock_TE_282834-4_1x04_P2.54mm_Horizontal; MPN KF128-2.54-4P
J4: Screw_Terminal_01x08_Bottom_Left; TerminalBlock_TE_282834-8_1x08_P2.54mm_Horizontal; MPN KF128-2.54-8P
J5: Screw_Terminal_01x06_Top_Right; TerminalBlock_TE_282834-6_1x06_P2.54mm_Horizontal; MPN KF128-2.54-6P
J6: 12Vpsu; TerminalBlock_bornier-2_P5.08mm; MPN WJ126V-5.0-2P; LCSC C8404
J7: Conn_01x01; PinHeader_1x01_P2.54mm_Vertical
J8: Screw_Terminal_01x06; TerminalBlock_TE_282834-6_1x06_P2.54mm_Horizontal; MPN KF128-2.54-6P
J9: Screw_Terminal_01x02; TerminalBlock_TE_282834-2_1x02_P2.54mm_Horizontal; MPN KF128-2.54-2P
J10: Micro_SD_Card_9P; Micro_SD_9+4P-SMD-16.1X14.5X1.85MM; MPN XKTF-015-N; LCSC C381082
J14: Barrel_Jack_Switch; BarrelJack_Wuerth_6941xx301002; MPN DC-005 5.5-2.0MM; LCSC C16214
JP1, JP11, JP13: SolderJumper_3_Bridged12; SolderJumper-3_P1.3mm_Bridged12_RoundedPad1.0x1.5mm
JP3: SolderJumper_3_Bridged12; SolderJumper-3_P1.3mm_Bridged2Bar12_RoundedPad1.0x1.5mm
Q1: DMG2305UX; SOT-23; MPN DMG2305UX-13; LCSC C144153
Q2: ALS-PT19; LED_0603_1608Metric; MPN ALS-PT19-315C/L177/TR8; LCSC C146233
Q7, Q8: MMBT4401; SOT-23; MPN MMBT4401LT1G; LCSC C31776
R3, R4, R11, R12, R16, R17, R22, R23, R26, R27, R29, R30, R32, R33, R34: 10KΩ; R_0603_1608Metric; MPN RC0603FR-0710KL; LCSC C98220
R7, R28: 1.2KΩ; R_0603_1608Metric; MPN RC0603FR-071K2L; LCSC C114605
R13: 2.2KΩ; R_0603_1608Metric; MPN RC0603FR-072K2L; LCSC C114662
R14, R15: 56KΩ; R_0603_1608Metric; MPN RC0603FR-0756KL; LCSC C114630
R21: 470Ω; R_0603_1608Metric; MPN RC0603FR-07470RL; LCSC C114669
R24: 4.7KΩ; R_0603_1608Metric; MPN RC0603FR-074K7L; LCSC C99782
R25, R31: 1KΩ; R_0603_1608Metric; MPN RC0603FR-071KL; LCSC C22548
SW1, SW2, SW3, SW8: SW_Push; SW_Push_1P1T-MP_NO_Horizontal_Alps_SKRTLAE010; MPN SKRTLAE010; LCSC C110293
SW4, SW5: SW_Push; SW_SPST_TL3305A; LCSC C174049
U1: AMS1117-3.3; SOT-223-3_TabPin2; MPN AMS1117-3.3; LCSC C426566
U3: ESP32-WROOM-32D; ESP32-WROOM-32; LCSC C473012
U4: DS18B20; TO-92_Inline; MPN DS18B20+; LCSC C9753
U5: AHT20; MPN AHT20; LCSC C503357

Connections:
3V3: C2.1, C3.1, C7.1, C8.2, C11.1, C38.2, D5.1 (K), D7.1 (K), D28.1 (K), J2.1, J5.3, J10.4 (VDD(3V3)), JP11.3 (B), JP13.1 (A), R4.2, R11.1, R12.2, R13.1, R22.1, R23.1, R24.2, R29.1, R30.1, R31.1, R32.1, R33.1, R34.1, U1.2 (VO), U3.2 (VDD), U4.3 (VDD), U5.2 (VDD); also elsewhere on the board
5V: JP1.3 (B), JP3.1 (A), JP11.1 (A), JP13.3 (B); also elsewhere on the board
5V-28V-unfused: F1.2, J6.1, J14.1
12V: JP1.1 (A), JP3.3 (B), Q1.2 (S); also elsewhere on the board
A0_ADC2_DAC2: U3.11 (IO26); also elsewhere on the board
A1_ADC2_DAC1: U3.10 (IO25); also elsewhere on the board
DTR: J5.6, Q8.2 (E), R26.2; also elsewhere on the board
GND: BZ1.2 (+), C1.2, C2.2, C3.2, C4.2, C5.2, C6.2, C7.2, C8.1, C9.2, C10.2, C11.2, C38.1, C39.2, D3.1 (K), D6.2 (A), D8.2 (A), D11.1 (K), J2.3, J3.2, J3.4, J5.1, J6.2, J10.6 (VSS(GND)), J10.10 (G4), J10.11 (G3), J10.12 (G1), J10.13 (G2), J14.2, Q1.1 (G), R3.2, R16.2, R17.2, SW1.2, SW2.2, SW3.2, SW4.2, SW5.2, SW8.2, U1.1 (GND), U3.1 (GND), U3.15 (GND), U3.38 (GND), U3.39 (GND), U4.1 (GND), U5.5 (GND); also elsewhere on the board
GPIO0: Q8.3 (C), SW5.1, SW8.1, U3.25 (IO0)
GPIO02: U3.24 (IO2)
IO4_A5_ADC2: U3.26 (IO4)
IO12_A11_ADC2: U3.14 (IO12)
IO13_A12_ADC2: J2.4, R25.1, U3.16 (IO13)
IO14_A6_ADC2: C5.1, R4.1, R7.2, U3.13 (IO14)
IO15_A8_ADC2: J10.2 (CD/D3(CS/SS)), R29.2, U3.23 (IO15)
IO16: BZ1.1 (-), R21.1, R21.2, U3.27 (IO16)
IO17: J2.2, R24.1, U3.28 (IO17), U4.2 (DQ)
IO21: U3.33 (IO21); also elsewhere on the board
IO27_A10_ADC2: U3.12 (IO27); also elsewhere on the board
IO32_A7_ADC1: U3.8 (IO32); also elsewhere on the board
IO33_A9_ADC1: J8.3, U3.9 (IO33)
IO34_A2_ADC1: C4.1, D5.2 (A), D6.1 (K), R14.2, R16.1, U3.6 (IO34)
IO35_A13_ADC1: C6.1, D7.2 (A), D8.1 (K), R15.2, R17.1, U3.7 (IO35)
IO36_A4_ADC1: C10.1, C39.1, D28.2 (A), Q2.1 (E), R3.1, R12.1, R28.2, U3.4 (SENSOR_VP)
IO39_A3_ADC1: U3.5 (SENSOR_VN); also elsewhere on the board
MISO: J8.4, J10.7 (DO_(MISO)), R34.2, U3.31 (IO19)
MOSI: J8.5, J10.3 (DI/CMD(MOSI)), R32.2, U3.30 (IO18)
unnamed: C1.1, JP3.2 (C), U1.3 (VI)
unnamed: D3.2 (A), R13.2
unnamed: D11.2 (A), R25.2
unnamed: D12.1 (K), J10.9 (CDN), R30.2
unnamed: D12.2 (A), R31.2
unnamed: F1.1, Q1.3 (D)
unnamed: JP13.2 (C), Q2.2 (C)
unnamed: Q7.1 (B), R26.1
unnamed: Q8.1 (B), R27.1
RESET: C9.1, Q7.3 (C), R11.2, SW2.1, SW4.1, U3.3 (EN); also elsewhere on the board
RTS: J7.1, Q7.2 (E), R27.2; also elsewhere on the board
RX_BRD: J5.4, U3.34 (RXD0/IO3); also elsewhere on the board
SCK: J8.6, J10.5 (SCLK), R33.2, U3.29 (IO5)
SCL: J8.1, R22.2, U3.36 (IO22), U5.3 (SCL); also elsewhere on the board
SDA: J8.2, R23.2, U3.37 (IO23), U5.4 (SDA); also elsewhere on the board
ST_BL_7: J4.7, JP1.2 (C), R15.1
ST_BL_8: J4.8, JP11.2 (C), R14.1
ST_LB_1: J3.1, R28.1, SW1.1
ST_LB_3: J3.3, R7.1, SW3.1
TX_BRD: J5.5, U3.35 (TXD0/IO1); also elsewhere on the board

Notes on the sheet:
https://webench.ti.com/power-designer/switching-regulator
Ver 1.0a (2020-08-26) - Added SolderJumber to input of AMS1117-3.3 Reg, with default 5V input
10k pull up resistor and 100nF debounce capacitor
Jumper LCSC C5305 LCSCweb https://lcsc.com/product-detail/Shunts-Jumpers_2-54mm-Short-hood_C5305.html https://www.futurlec.com/SwKnob.shtml https://www.futurlec.com/Switches/KNOB3.shtml https://www.aliexpress.com/item/10-Pcs-1S-Lipo-Battery-Balance-Charger-Cable-Molex-51005-Male-Female-Plug-2-0mm-P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
Fuse and Reverse polarity protection
Resistor power 2512 1w 1 2010 3/4w 0.75 1206 1/2w 0.5 1210 1/4w 0.25 0805 1/8w 0.125 0603 1/10w 0.1 0402 1/16w 0.0625 0201 1/20w 0.05
12V GND 3V3 GND
MOFSET switch
InputSwitch1
max 30 4.7v-30v
UART
Relay 1
Atten=3, effective measurement range of [ 150 - 2450 mV ] error = –60 60 9v - 16v Voltage Devider 56k - 10k 1V = 152 mV 9V = 1364 mV 10V = 1515 mV 11V = 1667 mV 12V = 1818 mV 13V = 1970 mV 14V = 2121 mV 15V = 2273 mV 16V = 2424 mV 17V = 2576 mV 18V = 2727 mV 19V = 2879 mV 20V = 3030 mV 21V = 3182 m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
at 0.3ma, Vf = vcc + <0.15V -0.15V to 3.45V https://datasheet.lcsc.com/szlcsc/Diodes-Incorporated-1N5819HW-7-F_C82544.pdf https://lcsc.com/product-detail/Schottky-Barrier-Diodes-SBD_DIODES_1N5819HW-7-F_1N5819HW-7-F_C82544.html
https://www.sparkfun.com/products/15663 https://cdn.sparkfun.com/assets/e/4/2/1/7/ESP32_Thing_Plus_v_2_0_Schematic.pdf https://learn.adafruit.com/huzzah32-esp32-breakout-board?view=all https://learn.adafruit.com/assets/74367 https://learn.adafruit.com/adafruit-huzzah32-esp32-feather?view=all https: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
Reset
GPIO0 Button
If DTR is LOW, toggling RTS from HIGH to LOW resets to run mode. if RTS is HIGH, toggling DTR from LOW to HIGH resets to bootloader.
Auto-Reset
Boot Mode Configuration Pin Default Boot Download GPIO0 1 1 0 U0TXD 1 1 x GPIO2 0 x 0 GPIO4 0 x x MTDO 1 x x GPIO5 1 1 x If U0TXD, GPIO2, GPIO5 are Floating, GPIO0 determines boot mode
Vmon1
LED
Button
Note: you can only read analog inputs on ADC #1 once WiFi has started
Input Only
Built in Pull-Down, use as output only
32KHz crystal
1-wire
Buzzer
DNP
Do not use, Built in Pull-Down
Do not use, Built in Pull-Up
Built in Pull-Up
voltage divider for 1V - 16V (Max 21V)
AHT20 temp/humidity
Vmon2
Bi-Directional MOFSET switch
1-wire temp
SDA on adafruit/sparkfun
I2C Pullup

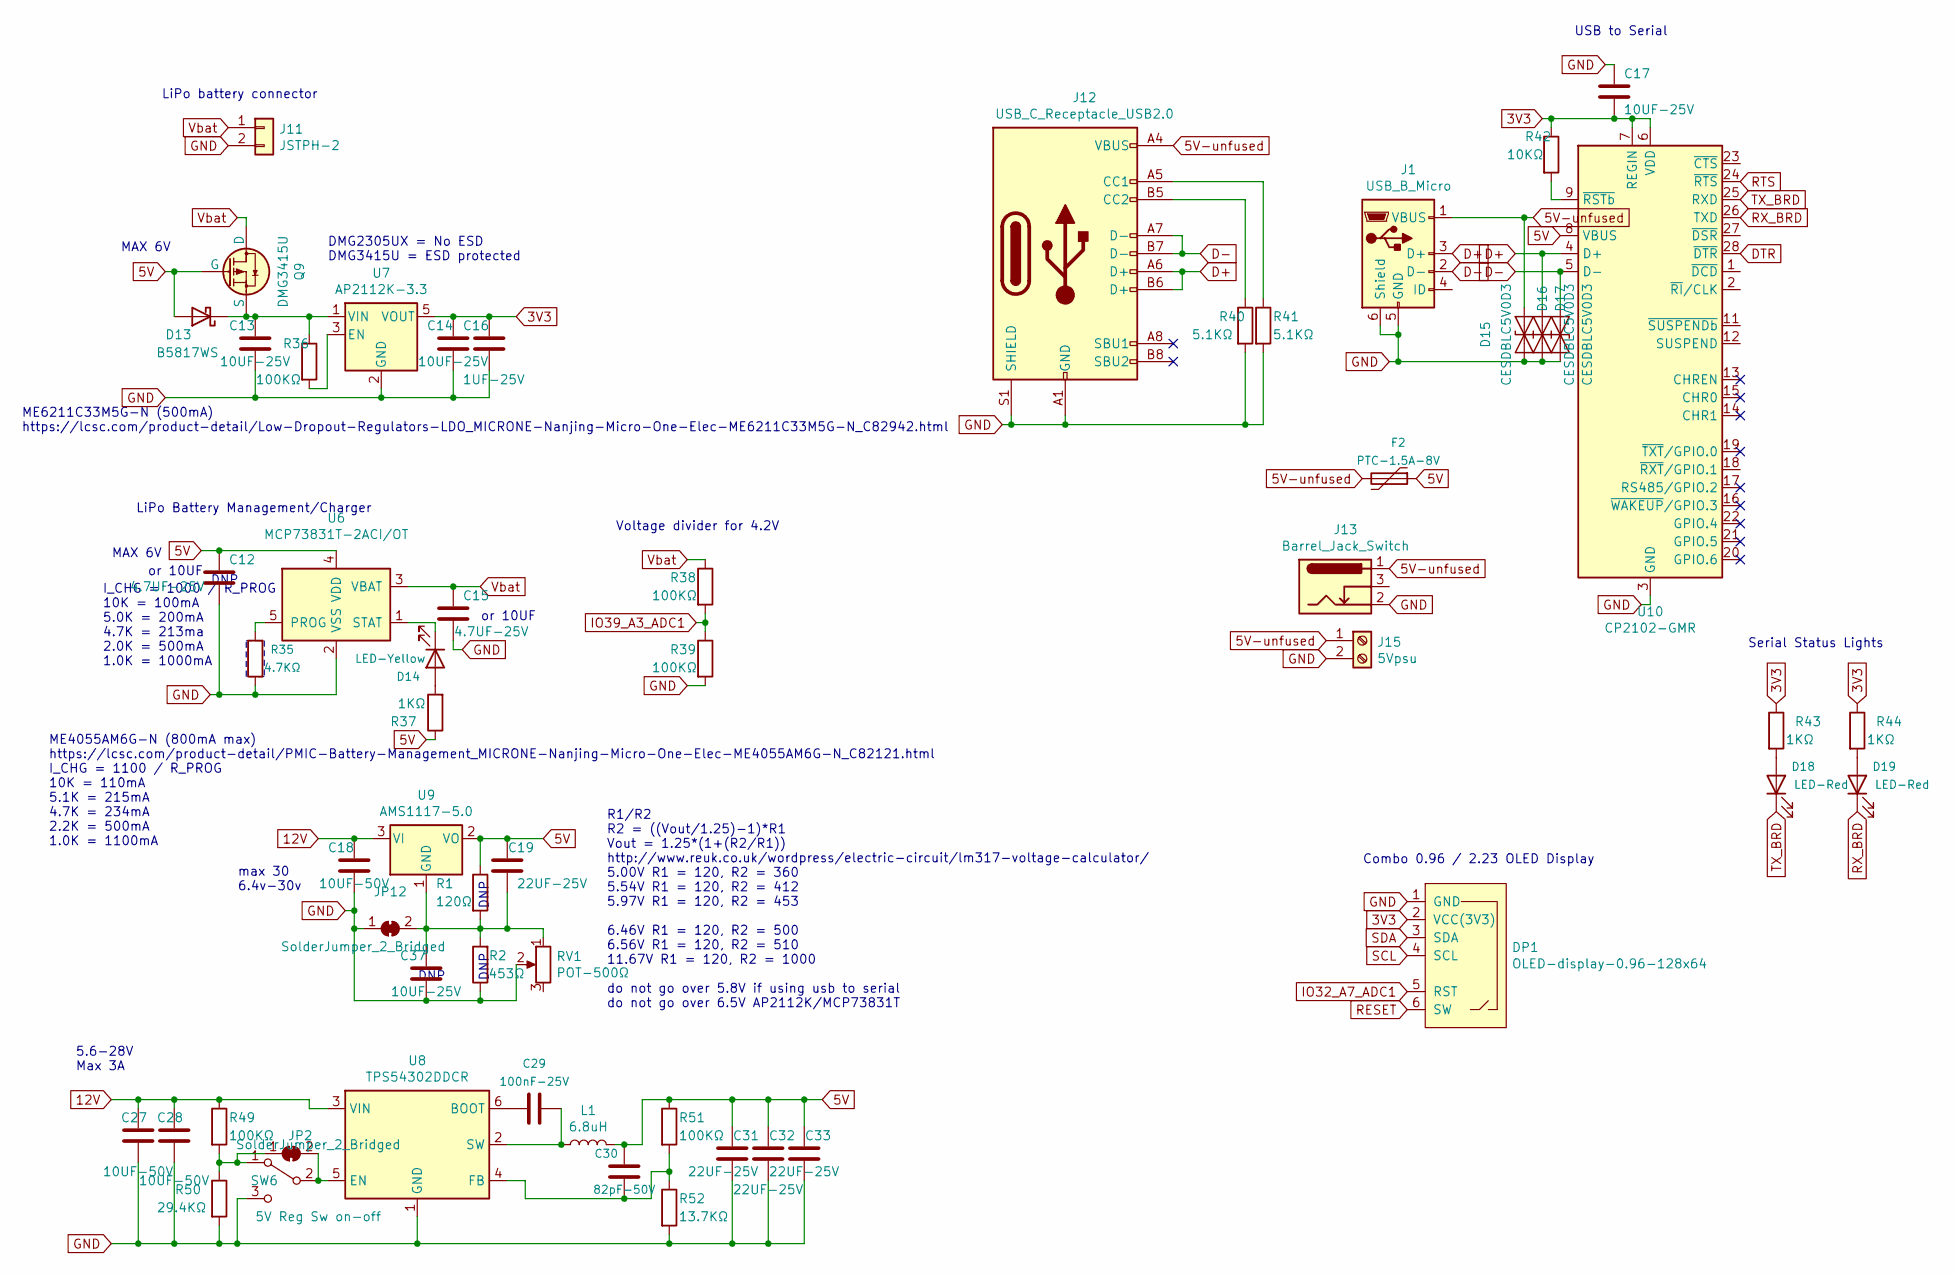
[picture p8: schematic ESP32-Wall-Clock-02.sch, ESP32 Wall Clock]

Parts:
C12, C15: 4.7UF-25V; C_0603_1608Metric; MPN CL10A475KA8NQNC; LCSC C69335
C13, C14, C17, C37: 10UF-25V; C_0603_1608Metric; MPN CL10A106MA8NRNC; LCSC C96446
C16: 1UF-25V; C_0603_1608Metric; MPN CL10B105KA8NNNC; LCSC C29936
C18, C27, C28: 10UF-50V; C_1206_3216Metric; MPN CL31A106KBHNNNE; LCSC C13585
C19, C31, C32, C33: 22UF-25V; C_0805_2012Metric; MPN CL21A226MAQNNNE; LCSC C45783
C29: 100nF-25V; C_0402_1005Metric; MPN CL05A104KA5NNNC; LCSC C100072
C30: 82pF-50V; C_0402_1005Metric; MPN CL05C820JB5NNNC; LCSC C13532
D13: B5817WS; D_SOD-323; MPN B5817WS-SJ; LCSC C114023
D14: LED-Yellow; LED_0603_1608Metric; MPN FC-DA1608HYK-588J; LCSC C84268
D15, D16, D17: CESDBLC5V0D3; D_SOD-323; MPN CESDBLC5V0D3; LCSC C47346
D18, D19: LED-Red; LED_0603_1608Metric; MPN FC-DA1608HRK-620D; LCSC C84263
DP1: OLED-display-0.96-128x64; OLED-display-0.96-128x64-2.23-128x32-combo
F2: PTC-1.5A-8V; Fuse_1812_4532Metric; MPN 1812L150ZR; LCSC C207071
J1: USB_B_Micro; USB_Micro-B_Korean_U-F-M5DD-Y-L; MPN U-F-M5DD-Y-L; LCSC C91146
J11: JSTPH-2; JST_PH_S2B-PH-K_1x02_P2.00mm_Horizontal; MPN S2B-PH-K-S; LCSC C49992
J12: USB_C_Receptacle_USB2.0; USB_C_Receptacle_HRO_TYPE-C-31-M-12; MPN TYPE-C-31-M-12; LCSC C165948
J13: Barrel_Jack_Switch; BarrelJack_Wuerth_6941xx301002; MPN DC-005 5.5-2.0MM; LCSC C16214
J15: 5Vpsu; TerminalBlock_bornier-2_P5.08mm; MPN WJ126V-5.0-2P; LCSC C8404
JP2: SolderJumper_2_Bridged; SolderJumper-2_P1.3mm_Bridged_RoundedPad1.0x1.5mm
JP12: SolderJumper_2_Bridged; SolderJumper-2_P1.3mm_Bridged2Bar_RoundedPad1.0x1.5mm
L1: 6.8uH; L_7.3x7.3_H4.5; MPN FXL0630-6R8-M; LCSC C167221
Q9: DMG3415U; SOT-23; MPN DMG3415U-7; LCSC C96616
R1: 120Ω; R_0603_1608Metric; MPN RC0603FR-07120RL; LCSC C114640
R2: 453Ω; R_0603_1608Metric; MPN RC0603FR-07453RL; LCSC C482871
R35: 4.7KΩ; R_0603_1608Metric; MPN RC0603FR-074K7L; LCSC C99782
R36, R38, R39, R49, R51: 100KΩ; R_0603_1608Metric; MPN RC0603FR-07100KL; LCSC C14675
R37, R43, R44: 1KΩ; R_0603_1608Metric; MPN RC0603FR-071KL; LCSC C22548
R40, R41: 5.1KΩ; R_0603_1608Metric; MPN RC0603FR-075K1L; LCSC C105580
R42: 10KΩ; R_0603_1608Metric; MPN RC0603FR-0710KL; LCSC C98220
R50: 29.4KΩ; R_0603_1608Metric; MPN RC0603FR-0729K4L; LCSC C137752
R52: 13.7KΩ; R_0603_1608Metric; MPN RC0603FR-0713K7L; LCSC C482771
RV1: POT-500Ω; Potentiometer_Bourns_TC33X_Vertical; MPN VG039NCHXTB501; LCSC C128556
SW6: 5V Reg Sw on-off; SW_SPDT_PCM12; MPN K3-1296S-E2; LCSC C136659
U6: MCP73831T-2ACI/OT; SOT-23-5; MPN MCP73831T-2ACI/OT; LCSC C424093
U7: AP2112K-3.3; SOT-23-5; MPN AP2112K-3.3TRG1; LCSC C51118
U8: TPS54302DDCR; SOT-23-6; MPN TPS54302DDCR; LCSC C311983
U9: AMS1117-5.0; SOT-223-3_TabPin2; MPN AMS1117-5.0; LCSC C473812
U10: CP2102-GMR; QFN-28-1EP_5x5mm_P0.5mm_EP3.35x3.35mm; MPN CP2102-GMR; LCSC C6568

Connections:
3V3: C14.1, C16.1, C17.2, DP1.2 (VCC(3V3)), R42.1, R43.1, R44.1, U7.5 (VOUT), U10.6 (VDD), U10.7 (REGIN); also elsewhere on the board
5V: C12.1, C19.1, C30.1, C31.1, C32.1, C33.1, D13.2 (A), F2.1, L1.2, Q9.1 (G), R1.1, R37.1, R51.1, U6.4 (VDD), U9.2 (VO), U10.8 (VBUS); also elsewhere on the board
5V-unfused: D15.2 (A2), F2.2, J1.1 (VBUS), J12.A4 (VBUS), J12.A9 (VBUS), J12.B4 (VBUS), J12.B9 (VBUS), J13.1, J15.1
12V: C18.1, C27.1, C28.1, R49.1, U8.3 (VIN), U9.3 (VI); also elsewhere on the board
D+: D16.2 (A2), J1.3 (D+), J12.A6 (D+), J12.B6 (D+), U10.4 (D+)
D-: D17.2 (A2), J1.2 (D-), J12.A7 (D-), J12.B7 (D-), U10.5 (D-)
DTR: U10.28 (~DTR); also elsewhere on the board
GND: C12.2, C13.2, C14.2, C15.2, C16.2, C17.1, C18.2, C27.2, C28.2, C31.2, C32.2, C33.2, C37.2, D15.1 (A1), D16.1 (A1), D17.1 (A1), DP1.1 (GND), J1.5 (GND), J1.6 (Shield), J11.2, J12.A1 (GND), J12.A12 (GND), J12.B1 (GND), J12.B12 (GND), J12.S1 (SHIELD), J13.2, J15.2, JP12.1 (A), R2.1, R35.1, R39.2, R40.2, R41.2, R50.2, R52.2, RV1.2, SW6.3 (C), U6.2 (VSS), U7.2 (GND), U8.1 (GND), U10.3 (GND), U10.29 (GND); also elsewhere on the board
IO32_A7_ADC1: DP1.5 (RST); also elsewhere on the board
IO39_A3_ADC1: R38.2, R39.1; also elsewhere on the board
unnamed: C13.1, D13.1 (K), Q9.2 (S), R36.1, U7.1 (VIN)
unnamed: C19.2, C37.1, JP12.2 (B), R1.2, R2.2, RV1.1, U9.1 (GND)
unnamed: C29.1, U8.6 (BOOT)
unnamed: C29.2, L1.1, U8.2 (SW)
unnamed: C30.2, R51.2, R52.1, U8.4 (FB)
unnamed: D14.1 (K), U6.1 (STAT)
unnamed: D14.2 (A), R37.2
unnamed: D18.2 (A), R43.2
unnamed: D19.2 (A), R44.2
unnamed: J12.A5 (CC1), R41.1
unnamed: J12.B5 (CC2), R40.1
unnamed: JP2.1 (A), R49.2, R50.1, SW6.1 (A)
unnamed: JP2.2 (B), SW6.2 (B), U8.5 (EN)
unnamed: R35.2, U6.5 (PROG)
unnamed: R36.2, U7.3 (EN)
unnamed: R42.2, U10.9 (~RSTb)
RESET: DP1.6 (SW); also elsewhere on the board
RTS: U10.24 (~RTS); also elsewhere on the board
RX_BRD: D19.1 (K), U10.26 (TXD); also elsewhere on the board
SCL: DP1.4 (SCL); also elsewhere on the board
SDA: DP1.3 (SDA); also elsewhere on the board
TX_BRD: D18.1 (K), U10.25 (RXD); also elsewhere on the board
Vbat: C15.1, J11.1, Q9.3 (D), R38.1, U6.3 (VBAT)

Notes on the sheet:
MAX 6V
I_CHG = 1000 / R_PROG 10K = 100mA 5.0K = 200mA 4.7K = 213ma 2.0K = 500mA 1.0K = 1000mA
DNP
or 10UF
ME4055AM6G-N (800mA max) https://lcsc.com/product-detail/PMIC-Battery-Management_MICRONE-Nanjing-Micro-One-Elec-ME4055AM6G-N_C82121.html I_CHG = 1100 / R_PROG 10K = 110mA 5.1K = 215mA 4.7K = 234mA 2.2K = 500mA 1.0K = 1100mA
DMG2305UX = No ESD DMG3415U = ESD protected
5.6-28V Max 3A
max 30 6.4v-30v
ME6211C33M5G-N (500mA) https://lcsc.com/product-detail/Low-Dropout-Regulators-LDO_MICRONE-Nanjing-Micro-One-Elec-ME6211C33M5G-N_C82942.html
R1/R2 R2 = ((Vout/1.25)-1)*R1 Vout = 1.25*(1+(R2/R1)) http://www.reuk.co.uk/wordpress/electric-circuit/lm317-voltage-calculator/ 5.00V R1 = 120, R2 = 360 5.54V R1 = 120, R2 = 412 5.97V R1 = 120, R2 = 453 6.46V R1 = 120, R2 = 500 6.56V R1 = 120, R2 = 510 11.67V R1 = 120, R2 = 1000 do not go over 5.8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
Voltage divider for 4.2V
Combo 0.96 / 2.23 OLED Display
LiPo battery connector
LiPo Battery Management/Charger
USB to Serial
Serial Status Lights

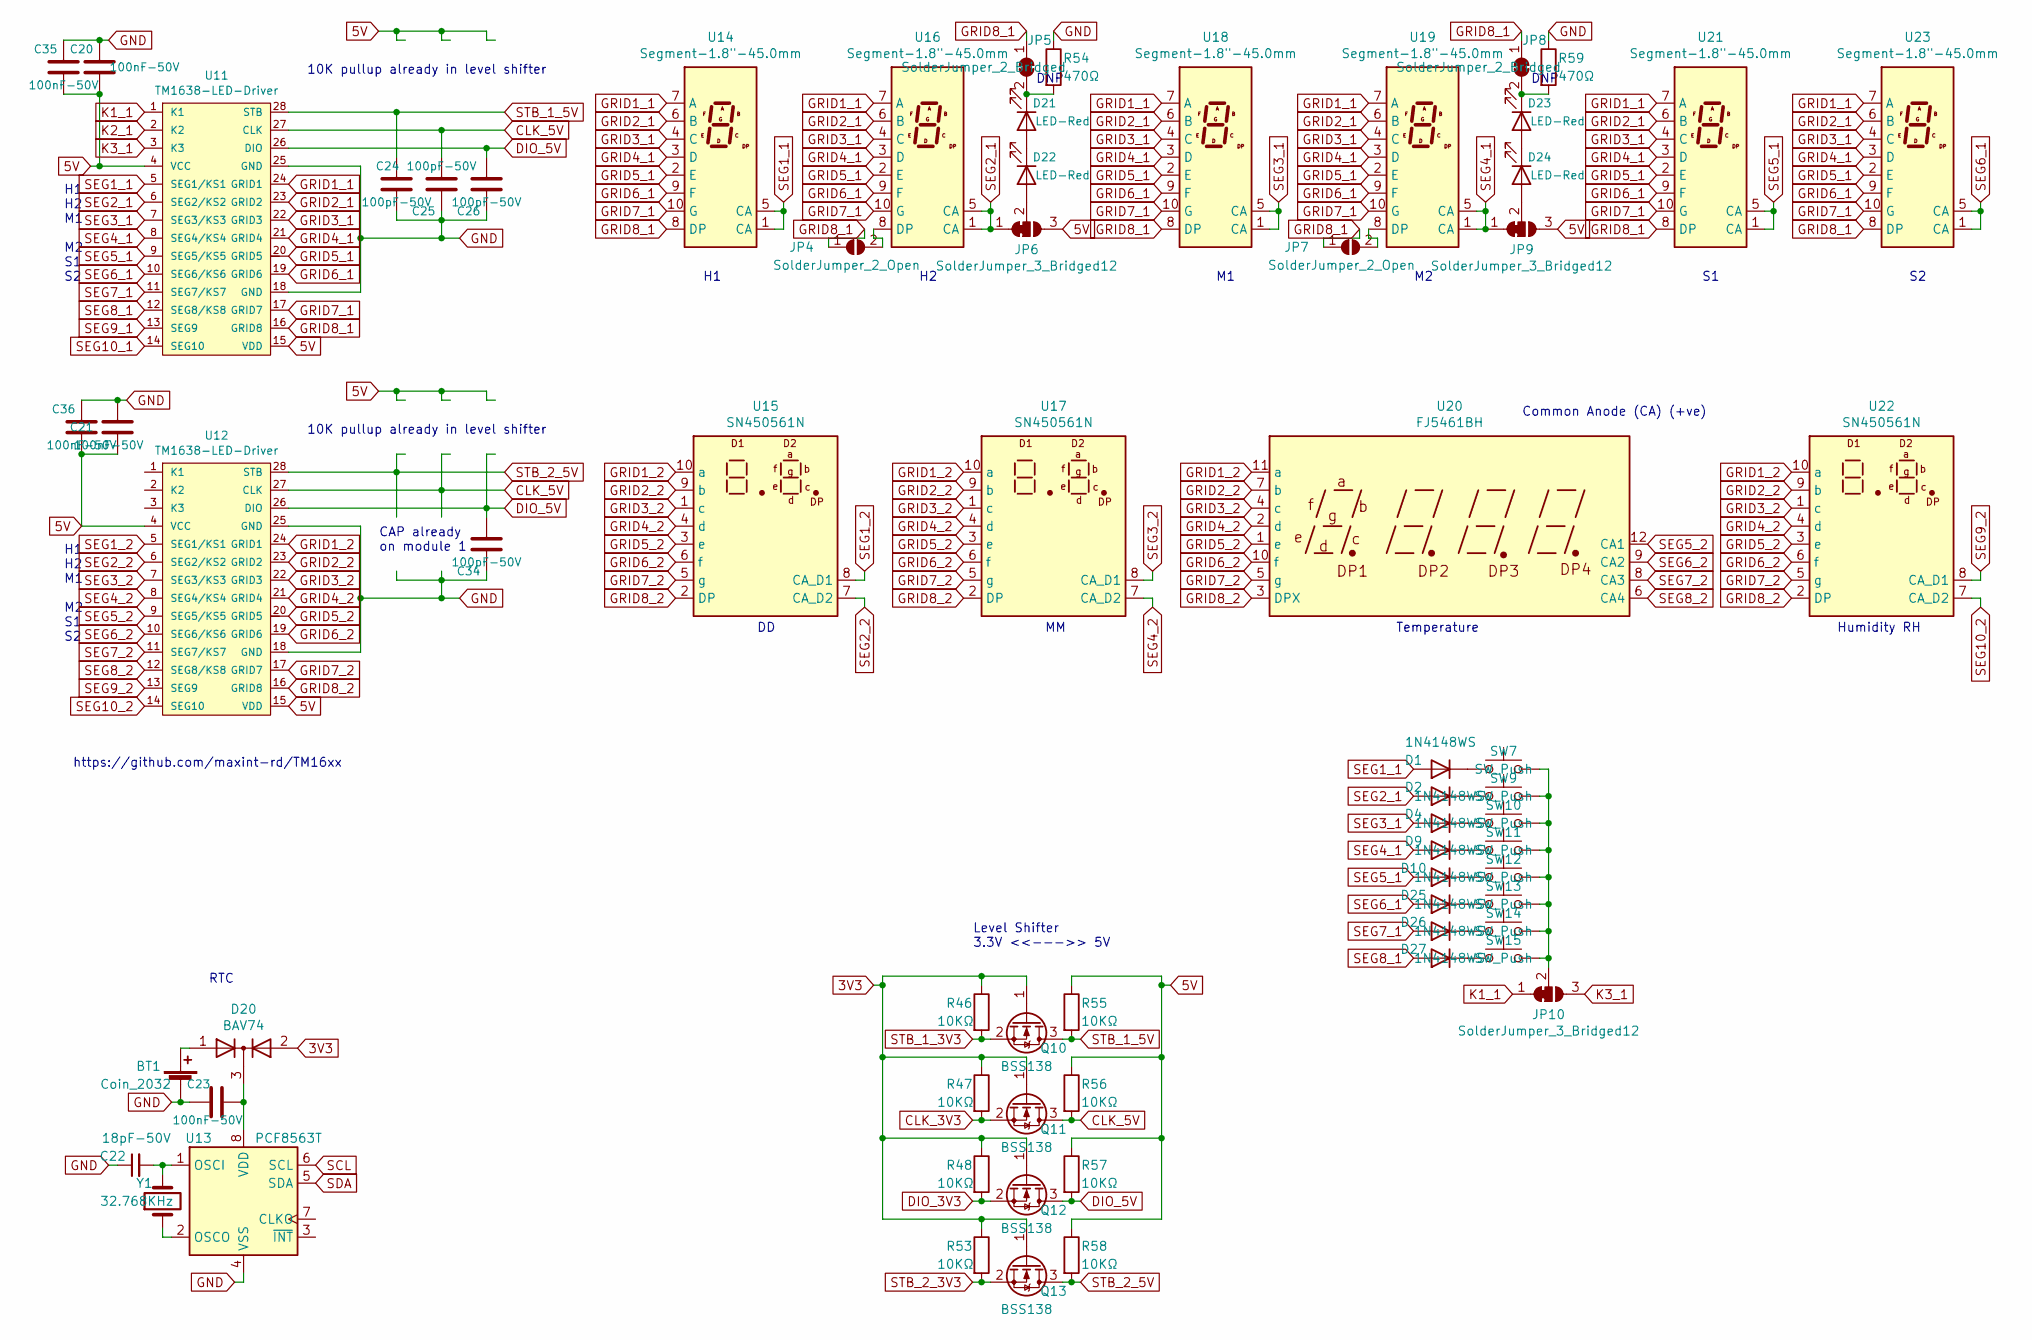
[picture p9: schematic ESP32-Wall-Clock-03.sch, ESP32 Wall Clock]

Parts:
BT1: Coin_2032; BatteryHolder_Keystone_1060_1x2032; MPN CR2032-BS-6-1; LCSC C70377
C20, C21, C23, C35, C36: 100nF-50V; C_0603_1608Metric; MPN AC0603KRX7R9BB104; LCSC C149620
C22: 18pF-50V; C_0402_1005Metric; MPN GCM1555C1H180JA16D; LCSC C126499
C24, C25, C26, C34: 100pF-50V; C_0402_1005Metric; MPN CL05C101JB5NNNC; LCSC C26409
D1, D2, D4, D9, D10, D25, D26, D27: 1N4148WS; D_SOD-323; MPN 1N4148WS; LCSC C2128
D20: BAV74; SOT-23; MPN BAV74; LCSC C68981
D21, D22, D23, D24: LED-Red; LED_0603_1608Metric; MPN FC-DA1608HRK-620D; LCSC C84263
JP4, JP7: SolderJumper_2_Open; SolderJumper-2_P1.3mm_Open_RoundedPad1.0x1.5mm
JP5, JP8: SolderJumper_2_Bridged; SolderJumper-2_P1.3mm_Bridged_RoundedPad1.0x1.5mm
JP6, JP9, JP10: SolderJumper_3_Bridged12; SolderJumper-3_P1.3mm_Bridged12_RoundedPad1.0x1.5mm
Q10, Q11, Q12, Q13: BSS138; SOT-23; MPN BSS138-7-F; LCSC C40912
R46, R47, R48, R53, R55, R56, R57, R58: 10KΩ; R_0603_1608Metric; MPN RC0603FR-0710KL; LCSC C98220
R54, R59: 470Ω; R_0603_1608Metric; MPN RC0603FR-07470RL; LCSC C114669
SW7, SW9, SW10, SW11, SW12, SW13, SW14, SW15: SW_Push; SW_Push_1P1T-MP_NO_Horizontal_Alps_SKRTLAE010; MPN SKRTLAE010; LCSC C110293
U11, U12: TM1638-LED-Driver; SOIC-28W_7.5x17.9mm_P1.27mm; MPN TM1638; LCSC C19187
U13: PCF8563T; SOIC-8_3.9x4.9mm_P1.27mm; MPN PCF8563T/5,518; LCSC C7440
U14, U16, U18, U19, U21, U23: Segment-1.8\"-45.0mm; SM471801N; MPN SM471801N; LCSC C193718
U15, U17, U22: SN450561N; MPN SN450561N; LCSC C193143
U20: FJ5461BH; CA56-12SRWA; MPN C38183; LCSC C38183
Y1: 32.768KHz; Crystal_SMD_3215-2Pin_3.2x1.5mm; MPN X321532768KGB2SI; LCSC C94279

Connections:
3V3: D20.2 (A), Q10.1 (G), Q11.1 (G), Q12.1 (G), Q13.1 (G), R46.1, R47.1, R48.1, R53.1; also elsewhere on the board
5V: C20.2, C21.2, C35.2, C36.2, JP6.3 (B), JP9.3 (B), R55.1, R56.1, R57.1, R58.1, U11.4 (VCC), U11.15 (VDD), U12.4 (VCC), U12.15 (VDD); also elsewhere on the board
A0_ADC2_DAC2: Q11.2 (S), R47.2; also elsewhere on the board
A1_ADC2_DAC1: Q12.2 (S), R48.2; also elsewhere on the board
CLK_5V: C25.1, Q11.3 (D), R56.2, U11.27 (CLK), U12.27 (CLK)
DIO_5V: C26.1, C34.1, Q12.3 (D), R57.2, U11.26 (DIO), U12.26 (DIO)
GND: BT1.2 (-), C20.1, C21.1, C22.1, C23.2, C24.2, C25.2, C26.2, C34.2, C35.1, C36.1, R54.1, R59.1, U11.18 (GND), U11.25 (GND), U12.18 (GND), U12.25 (GND), U13.4 (VSS); also elsewhere on the board
GRID1_1: U11.24 (GRID1), U14.7 (A), U16.7 (A), U18.7 (A), U19.7 (A), U21.7 (A), U23.7 (A)
GRID1_2: U12.24 (GRID1), U15.10 (a), U17.10 (a), U20.11 (a), U22.10 (a)
GRID2_1: U11.23 (GRID2), U14.6 (B), U16.6 (B), U18.6 (B), U19.6 (B), U21.6 (B), U23.6 (B)
GRID2_2: U12.23 (GRID2), U15.9 (b), U17.9 (b), U20.7 (b), U22.9 (b)
GRID3_1: U11.22 (GRID3), U14.4 (C), U16.4 (C), U18.4 (C), U19.4 (C), U21.4 (C), U23.4 (C)
GRID3_2: U12.22 (GRID3), U15.1 (c), U17.1 (c), U20.4 (c), U22.1 (c)
GRID4_1: U11.21 (GRID4), U14.3 (D), U16.3 (D), U18.3 (D), U19.3 (D), U21.3 (D), U23.3 (D)
GRID4_2: U12.21 (GRID4), U15.4 (d), U17.4 (d), U20.2 (d), U22.4 (d)
GRID5_1: U11.20 (GRID5), U14.2 (E), U16.2 (E), U18.2 (E), U19.2 (E), U21.2 (E), U23.2 (E)
GRID5_2: U12.20 (GRID5), U15.3 (e), U17.3 (e), U20.1 (e), U22.3 (e)
GRID6_1: U11.19 (GRID6), U14.9 (F), U16.9 (F), U18.9 (F), U19.9 (F), U21.9 (F), U23.9 (F)
GRID6_2: U12.19 (GRID6), U15.6 (f), U17.6 (f), U20.10 (f), U22.6 (f)
GRID7_1: U11.17 (GRID7), U14.10 (G), U16.10 (G), U18.10 (G), U19.10 (G), U21.10 (G), U23.10 (G)
GRID7_2: U12.17 (GRID7), U15.5 (g), U17.5 (g), U20.5 (g), U22.5 (g)
GRID8_2: U12.16 (GRID8), U15.2 (DP), U17.2 (DP), U20.3 (DPX), U22.2 (DP)
IO21: Q13.2 (S), R53.2; also elsewhere on the board
IO27_A10_ADC2: Q10.2 (S), R46.2; also elsewhere on the board
K1_1: JP10.1 (A), U11.1 (K1)
K2_1: U11.2 (K2)
K3_1: JP10.3 (B), U11.3 (K3)
unnamed: BT1.1 (+), D20.1 (A)
unnamed: C22.2, U13.1 (OSCI), Y1.2
unnamed: C23.1, D20.3 (K), U13.8 (VDD)
unnamed: D1.1 (K), SW7.1
unnamed: D2.1 (K), SW9.1
unnamed: D4.1 (K), SW10.1
unnamed: D9.1 (K), SW11.1
unnamed: D10.1 (K), SW12.1
unnamed: D21.1 (K), JP5.2 (B), R54.2
unnamed: D21.2 (A), D22.1 (K)
unnamed: D22.2 (A), JP6.2 (C)
unnamed: D23.1 (K), JP8.2 (B), R59.2
unnamed: D23.2 (A), D24.1 (K)
unnamed: D24.2 (A), JP9.2 (C)
unnamed: D25.1 (K), SW13.1
unnamed: D26.1 (K), SW14.1
unnamed: D27.1 (K), SW15.1
unnamed: JP10.2 (C), SW7.2, SW9.2, SW10.2, SW11.2, SW12.2, SW13.2, SW14.2, SW15.2
unnamed: U13.2 (OSCO), Y1.1
SCL: U13.6 (SCL); also elsewhere on the board
SDA: U13.5 (SDA); also elsewhere on the board
SEG1_2: U12.5 (SEG1/KS1), U15.8 (CA_D1)
SEG2_2: U12.6 (SEG2/KS2), U15.7 (CA_D2)
SEG3_2: U12.7 (SEG3/KS3), U17.8 (CA_D1)
SEG4_2: U12.8 (SEG4/KS4), U17.7 (CA_D2)
SEG5_2: U12.9 (SEG5/KS5), U20.12 (CA1)
SEG6_2: U12.10 (SEG6/KS6), U20.9 (CA2)
SEG7_1: D26.2 (A), U11.11 (SEG7/KS7)
SEG7_2: U12.11 (SEG7/KS7), U20.8 (CA3)
SEG8_1: D27.2 (A), U11.12 (SEG8/KS8)
SEG8_2: U12.12 (SEG8/KS8), U20.6 (CA4)
SEG9_1: U11.13 (SEG9)
SEG9_2: U12.13 (SEG9), U22.8 (CA_D1)
SEG10_1: U11.14 (SEG10)
SEG10_2: U12.14 (SEG10), U22.7 (CA_D2)
STB_1_5V: C24.1, Q10.3 (D), R55.2, U11.28 (STB)
STB_2_5V: Q13.3 (D), R58.2, U12.28 (STB)

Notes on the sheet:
H1 H2 M1 M2 S1 S2
Level Shifter 3.3V <<--->> 5V
10K pullup already in level shifter
DNP
CAP already on module 1
Humidity RH
Temperature
Common Anode (CA) (+ve)
https://github.com/maxint-rd/TM16xx
RTC

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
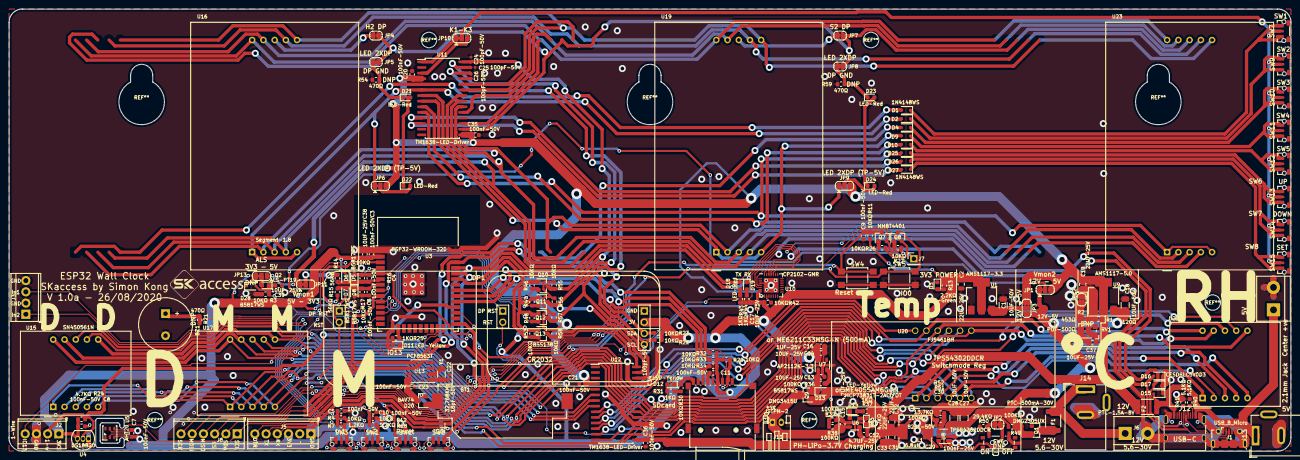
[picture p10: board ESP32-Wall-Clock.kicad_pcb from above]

Board: 2 copper layers, 290.0 x 100.0 mm, 194 parts (0 on the bottom side), 123 nets.
